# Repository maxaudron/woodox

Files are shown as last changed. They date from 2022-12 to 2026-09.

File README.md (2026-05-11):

# Woodox Firmware

Embedded Rust firmware for an analog hall-effect keyboard, targeting the RP2040 (Cortex-M0+). Runs bare-metal with `no_std`.

## Architecture

The firmware runs on both RP2040 cores simultaneously. Core 1 continuously scans hall-effect switches through analog multiplexers and ADC. Core 0 runs the USB HID stack and sends keyboard reports to the host at 1ms intervals. Switch state is shared between cores via static global memory, avoiding lock overhead.

## Workspace

The project is split into two crates:

### `board`

Hardware-specific code that directly interfaces with RP2040 peripherals.

- **`main.rs`** -- Entry point. Initializes clocks, GPIO pins, ADC, multiplexers, and the USB bus. Spawns the scan loop on core 1 and the USB loop on core 0.
- **`scan.rs`** -- Scan loop running on core 1. Iterates through all multiplexer channels, reads ADC values for each switch, and updates switch state.
- **`usb.rs`** -- USB loop running on core 0. Reads the global keyboard state every 1ms and sends NKRO HID reports to the host.
- **`hardware/mux.rs`** -- Driver for the CD74HC4067 16-channel analog multiplexer. Selects channels by setting four GPIO pins to the binary representation of the channel number.
- **`hardware/adc.rs`** -- Trait and implementation for reading raw values from the RP2040 ADC. Supports reading a single channel or all multiplexer inputs in sequence.
- **`dma.rs`** -- Work-in-progress DMA configuration for ADC transfers. Not currently used in the main loop.
- **`led/mod.rs`** -- Commented-out WS2812 LED driver using PIO. Not currently active.

### `library` (`woodox-lib`)

Platform-independent logic. Can be tested on the host machine.

- **`matrix/switch.rs`** -- Core switch logic. Each switch tracks its position, press/release state, and hold timing. Supports configurable actuation and release points. Implements rapid trigger, which dynamically fires press/release events based on relative travel distance rather than fixed thresholds.
- **`matrix/hall.rs`** -- Lookup table that converts raw 8-bit ADC values to physical travel distance in 0.1mm increments, based on the hall-effect sensor response curve.
- **`matrix/keys.rs`** -- Global keymap and keyboard state. Defines key types: regular keycodes, layer switching, layer-tap (layer on hold / keycode on tap), key-tap (keycode on hold / different keycode on tap), and grave-escape. Resolves key actions by walking down the layer stack.
- **`matrix/mod.rs`** -- Scan and ScanOrder structs that map physical switch positions (mux ID + channel) to their logical index in the keymap.
- **`layout/mod.rs`** -- Macros (`switches!`, `keymap!`, `layer!`, `key!`) for declaratively defining keyboard layouts at compile time.
- **`layout/macropad.rs`** -- Default layout for an 8-key macropad with 1 multiplexer. Defines the physical switch wiring and a two-layer keymap.

## Hardware

- **MCU**: RP2040 (dual Cortex-M0+ at 125 MHz, 12 MHz external crystal)
- **Switches**: Analog hall-effect sensors read via ADC
- **Multiplexers**: CD74HC4067 (16-channel analog mux), selecting switches for ADC reading
- **USB**: Native RP2040 USB with NKRO keyboard HID
- **LEDs**: WS2812 via PIO (currently disabled)

## Features

- `macropad` (default) -- Builds with the 8-key macropad layout.
- `timers` -- Enables microsecond-precision scan loop timing via the hardware timer.

## Building

Requires the `thumbv6m-none-eabi` target:

```sh
rustup target add thumbv6m-none-eabi
cargo build --release -p woodox
```

## Flashing

Uses `probe-run` via cargo runner, or `cargo-embed` with the provided `Embed.toml`:

```sh
cargo embed --release -p woodox
```

Debugger protocol is SWD at 20 MHz. RTT logging is enabled with `defmt` output.

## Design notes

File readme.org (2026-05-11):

#+title: Readme

* Decisions
** MUX controll central vs seperate
We can either control each mux on it's own, taking up significantly more pins
or have them be controlled all at the same time

- Much simpler routing
- less traces

- customize matrix scanning

** Split vs Lefty logic
either controller on each hand, or controller only on one hand

*** Split
- can use more mux
- lower latency?
- more keys
- mirror PCB

CD74HC4051
  
*** Lefty
- less cost
- simpler?
- analog signals over longer wire
  - potential interference?

- sepperate PCB designs
  
* TODOs
** TODO connect mux com only to uneven GPIO pins for PWM input
** DONE add pull up resistors to mux com
** DONE adjust value of drv5057
A3 uses ~25% of the messuring range in one direction
A2 would use ~50%
A1 would use 100%, but might clip.
** DONE switch to drv5056A2
** TODO Use same pins for all mux selects
** TODO matrix to keycode conversion
** TODO usb hid impl
https://github.com/dlkj/usbd-human-interface-device

* Magnet distance lookup table
3.25V VCC
3.00V @ 2.25mm = 24.12mT
0.95V @ 6.25mm =  3.52mT

#+begin_src python :python3.10 :results output
import math

R = 1.75
D = 4
z = 2.25
r = 24.12
B = - ( (2*r) / ( ( z / math.sqrt( (R**2) + (z**2) )) - ( (D+z) / math.sqrt( (R**2) + ((D+z)**2) ) ) ) )
print(B)
#+end_src

#+RESULTS:
: 277.8612937046934

** lookup table
#+begin_src python :python python3.10 :results output
import math
import numpy as np

Z = np.linspace(0.1, 10, 100)
B = 0.38
R = 1.75
D = 4

def flux(z):
    return (((B/2)*( ( (D+z) / math.sqrt((R**2) + ((D+z)**2)) )  -  ( z / math.sqrt((R**2)+(z**2)) )))*1000)

def voltage(x):
    return (600 + x * (100))

def value(x):
    return x / (3300.0 / 256.0)

flux_vec = np.vectorize(flux)
voltage_vec = np.vectorize(voltage)
value_vec = np.vectorize(value)

prev = 0
for z in Z:
    z = round(z, 2)
    y = float(flux_vec(z))
    v = float(voltage_vec(y))
    value = float(value_vec(v))
    value = round(value)
    print(str(value) + "..=" + str(prev-1) + " => " + str(int(z * 10)) + ",")
    prev = value
#+end_src

#+RESULTS:
#+begin_example
1318..=-1 => 1,
1240..=1317 => 2,
1163..=1239 => 3,
1088..=1162 => 4,
1015..=1087 => 5,
946..=1014 => 6,
880..=945 => 7,
819..=879 => 8,
761..=818 => 9,
706..=760 => 10,
656..=705 => 11,
610..=655 => 12,
567..=609 => 13,
528..=566 => 14,
492..=527 => 15,
459..=491 => 16,
429..=458 => 17,
401..=428 => 18,
375..=400 => 19,
352..=374 => 20,
331..=351 => 21,
312..=330 => 22,
294..=311 => 23,
277..=293 => 24,
262..=276 => 25,
248..=261 => 26,
236..=247 => 27,
224..=235 => 28,
213..=223 => 29,
203..=212 => 30,
194..=202 => 31,
186..=193 => 32,
178..=185 => 33,
170..=177 => 34,
164..=169 => 35,
157..=163 => 36,
151..=156 => 37,
146..=150 => 38,
141..=145 => 39,
136..=140 => 40,
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
#+end_example

** graph
#+NAME: magnets
|       B |    R | D |
|---------+------+---|
|    0.38 | 1.75 | 4 |
|    0.28 | 1.75 | 4 |

#+begin_src python :python python3.10 :results file :exports both :var data=magnets
import math
import matplotlib.pyplot as plt
import numpy as np

for line in data:
    Z = np.linspace(0.1, 10, 100)
    B = line[0]
    R = line[1]
    D = line[2]

    def f(z):
        r = (((B/2)*( ( (D+z) / math.sqrt((R**2) + ((D+z)**2)) )  -  ( z / math.sqrt((R**2)+(z**2)) )))*1000)
        if z == 2.0:
            plt.annotate('A=' + str(z) + "," + str(round(r, 2)), xy=(z, r), xytext=(z+1, r+1))
        if z == 6.3:
            plt.annotate('B=' + str(z) + "," + str(round(r, 2)), xy=(z, r), xytext=(z+1, r+1))
        return r

    x = np.vectorize(f)
    plt.plot(Z, x(Z), label="B = " + str(B))

plt.xlabel("mm")
plt.ylabel("mT")
plt.legend()
filename = "plot.png"
plt.savefig(filename)
return(filename)
#+end_src

#+RESULTS:


* Parts
LED Controller https://jlcpcb.com/partdetail/3305937-IS31FL3741A_QFLS4TR/C2940604

Multiplexer https://www.ti.com/lit/ds/symlink/cd74hc4067.pdf

Example rp2040 usage https://proto-pic.co.uk/content/RPI-PICO-R3-PUBLIC-SCHEMATIC.pdf

rp2040 https://datasheets.raspberrypi.com/rp2040/rp2040-datasheet.pdf

** Hall Sensor
https://www.ti.com/sensors/magnetic-sensors/linear-hall-effect-sensors/overview.html

DRV5055A3 SOT-23
https://www.ti.com/lit/ds/symlink/drv5055.pdf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

35 keys per side

DRV5057
https://www.ti.com/lit/ds/symlink/drv5057.pdf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

https://www.digikey.de/en/product-highlight/s/sunled/reverse-mount-rgb-plcc-smd-led

13,200 Gauss
1320mT

3.5mm diameter x 4 thiccness
z from 2.25mm to 6.25mm

Divide[13200,2](Divide[D + 4mm,Sqrt[Power[\(40)0.5 * 3.5mm\(41),2]+ \(40)D + 4mm\(41)]] - Divide[D,Sqrt[Power[\(40)0.5 * 3.5mm\(41),2]+ Power[D,2]]])

#+begin_src gnuplot
B = 1480
C = 4.7625
T = 12.7

plot [D = -20 :20] (B/2)*( ( ( D + T ) / sqrt( (0.5*C)**2 + (D+T)**2 ) ) - ( D / sqrt(0.5*C)**2 + D**2 ) )
#+end_src

https://crocus-technology.com/basic-magnetic-field-calculator/

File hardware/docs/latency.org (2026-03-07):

#+title: Latency

* Thought dumb
#+begin_src
[00:14:40] <+audron> well, this latency messuring stuff is a bit more complicated
[00:15:16] <+audron> the on-chip timer does an ok job but i have random outliers that i'm not sure with
[00:15:38] <+audron> that could either be somethings really stupid i did, or just be random
[00:17:59] <+audron> the switch scanning loop i'm messuring is on a sepperate core and should be pretty much totally isolated but there might still be some weird interactions by the timer registers themsselfs, or the logging / formatting library
[00:18:31] <+audron> and messuring off-device is a meh buisness too
[00:19:02] <+audron> some other guys i've read messure the whole round trip off caps-lock pressed, os working on it, and the led change reported back
[00:19:38] <+audron> which i guess is fine to compare latency between units on the same setup, but is entirely uncomparable between systems
[00:20:07] <+audron> and also non of the ones i've seen thus far actually test how the system reacts with multiple button presses
[00:20:28] <+audron> guess i gotta make my own...
[00:20:31] -*- audron sighs
#+end_src

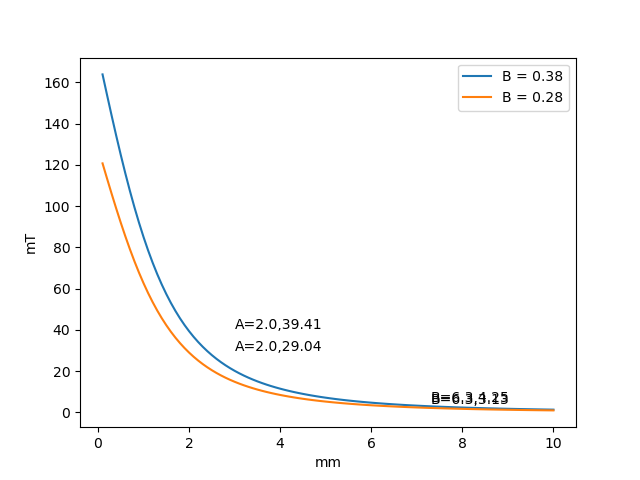
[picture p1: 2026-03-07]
hardware/docs/distance_magnetic_plot.png

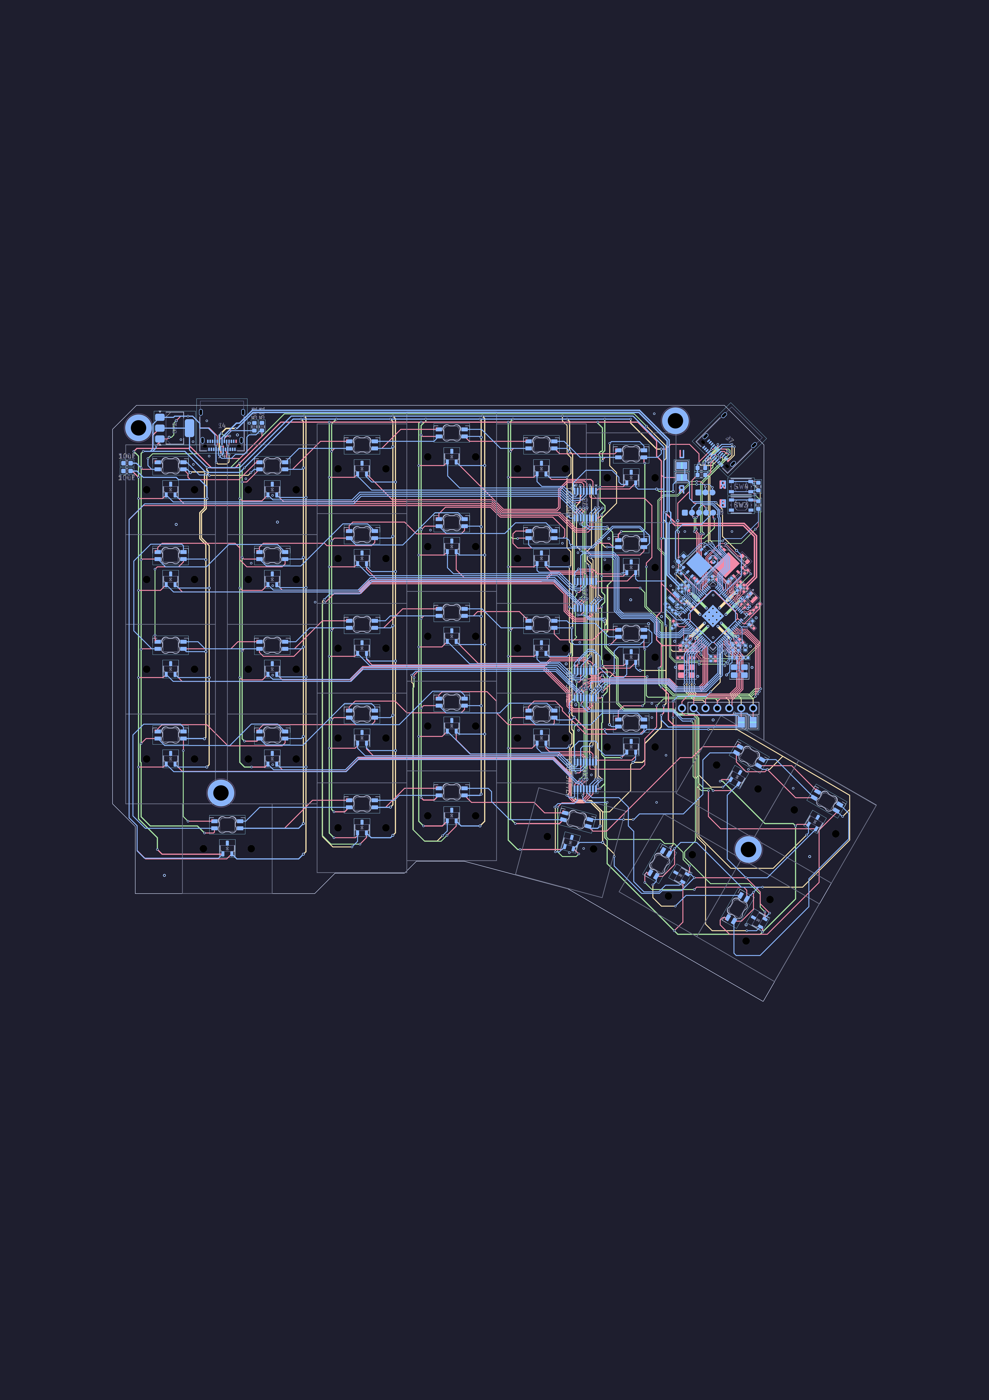
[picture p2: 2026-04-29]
hardware/woodox/pcb.webp

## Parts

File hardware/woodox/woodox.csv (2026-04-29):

Reference | Qty | Value | IPN | DNP | Exclude from BOM | Exclude from Board | Footprint | Datasheet | MPN | Manufacturer_Name | Manufacturer_Part_Number
Y2,Y3 | 2 | ABM8-272-T3 | CLK-000062 |  |  |  | Crystal:Crystal_SMD_3225-4Pin_3.2x2.5mm
U64,U79 | 2 | RP2350_80QFN | ICS-000063 |  |  |  | RP2350_80QFN_minimal:RP2350-QFN-80-1EP_10x10_P0.4mm_EP3.4x3.4mm_ThermalVias
U34,U35,U36,U37,U73,U74,U75,U76 | 8 | 74HC4051 | ICS-000064 |  |  |  | Package_SO:TSSOP-16_4.4x5mm_P0.65mm | http://www.ti.com/lit/ds/symlink/cd74hc4051.pdf | CD74HC4051PWR
U33,U72 | 2 | NCP1117-3.3_SOT223 | PWR-000043 |  |  |  | Package_TO_SOT_SMD:SOT-223-3_TabPin2 | http://www.onsemi.com/pub_link/Collateral/NCP1117-D.PDF | NCP1117LPST33T3G
U25,U49 | 2 | W25Q128JVP | ICS-000065 |  |  |  | Package_SON:WSON-8-1EP_6x5mm_P1.27mm_EP3.4x4.3mm | http://www.winbond.com/resource-files/w25q128jv_dtr%20revc%2003272018%20plus.pdf
U10 | 1 | OLED_256x64_I2C | MIS-000056 |  |  |  | lib:OLED_256x64_I2C |  | HEADER
U1,U2,U3,U4,U5,U6,U7,U8,U9,U11,U12,U13,U14,U15,U16,U17,U18,U19,U20,U21,U22,U23,U24,U26,U27,U28,U29,U30,U31,U32,U38,U39,U40,U41,U42,U43,U44,U45,U46,U47,U48,U50,U51,U52,U53,U54,U55,U56,U57,U58,U59,U60,U61,U62,U63,U65,U66,U67,U68,U69,U70,U71,U77,U78 | 64 | DRV5057A3 | ICS-000049 |  |  |  | lib:DRV505x | https://www.ti.com/lit/ds/symlink/drv5057.pdf | DRV5057A3
SW1,SW2,SW3,SW4 | 4 | SW_Push | MEC-000040 |  |  |  | Button_Switch_SMD:SW_Push_1P1T_NO_Vertical_Wuerth_434133025816
R24,R25,R27,R28 | 4 | 27 | RES-000070 |  |  |  | Resistor_SMD:R_0402_1005Metric
R22,R26 | 2 | 33 | RES-000071 |  |  |  | Resistor_SMD:R_0402_1005Metric
R17,R18,R19,R20 | 4 | 56k | RES-000072 |  |  |  | Resistor_SMD:R_0402_1005Metric |  | ERJ-3EKF1002V
R11,R13 | 2 | DNF |  | DNP |  |  | Resistor_SMD:R_0402_1005Metric |  | ERJ-3EKF1002V
R6,R7,R14,R15 | 4 | 5k1 | RES-000015 |  |  |  | Resistor_SMD:R_0402_1005Metric |  | ERJ-3EKF5101V
R1,R2,R12,R16,R21,R23 | 6 | 1k | RES-000011 |  |  |  | Resistor_SMD:R_0402_1005Metric
LED1,LED2,LED3,LED4,LED5,LED6,LED7,LED8,LED9,LED10,LED11,LED12,LED13,LED14,LED15,LED16,LED17,LED18,LED19,LED20,LED21,LED22,LED23,LED24,LED25,LED26,LED27,LED28,LED29,LED30,LED31,LED32,LED33,LED34,LED35,LED36,LED37,LED38,LED39,LED40,LED41,LED42,LED43,LED44,LED45,LED46,LED47,LED48,LED49,LED50,LED51,LED52,LED53,LED54,LED55,LED56,LED57,LED58,LED59,LED60,LED61,LED62,LED63,LED64 | 64 | MX_SK6812MINI-E | DIO-000012 |  |  |  | lib:LED_MX_SK6812MINI-R |  | SK6812MINI-E
L2,L3 | 2 | 3.3u | IND-000067 |  |  |  | RP2350_80QFN_minimal:L_pol_2016 |  | AOTA-B201610S3R3-101-T
J6,J7 | 2 | USB_C_Interlink | CON-000041 |  |  |  | Connector_USB:USB_C_Receptacle_Amphenol_12401610E4-2A | https://www.usb.org/sites/default/files/documents/usb_type-c.zip | 12401832E402A
J2,J4 | 2 | USB_C_To_Host | CON-000041 |  |  |  | Connector_USB:USB_C_Receptacle_Amphenol_12401610E4-2A | https://www.usb.org/sites/default/files/documents/usb_type-c.zip | 12401832E402A
C40,C41,C42,C43 | 4 | 15p | CAP-000069 |  |  |  | Capacitor_SMD:C_0402_1005Metric
C14,C17,C24,C25 | 4 | 4.7u | CAP-000024 |  |  |  | Capacitor_SMD:C_0402_1005Metric
C12,C13,C21,C22 | 4 | 4.7u | CAP-000024 |  |  |  | RP2350_80QFN_minimal:C_0402_1005Metric_small_pads
C6,C10,C16,C20 | 4 | 10uF | CAP-000021 |  |  |  | Capacitor_SMD:C_0402_1005Metric |  | GRM155R60J106ME15D
C4,C5,C15,C18,C19,C23,C26,C27,C32,C33,C34,C35,C36,C37,C38,C39,C44,C45,C46,C47,C48,C49,C50,C51 | 24 | 100n | CAP-000025 |  |  |  | Capacitor_SMD:C_0402_1005Metric

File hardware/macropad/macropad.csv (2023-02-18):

Item | Qty | Reference(s) | Value | LibPart | Footprint | Datasheet | Description | Height | MPN | Manufacturer_Name | Manufacturer_Part_Number | Mouser Part Number | Mouser Price/Stock
1 | 10 | C1, C7, C8, C9, C10, C12, C13, C14, C15, C16 | 0.1uF | Device:C_Small | Capacitor_SMD:C_0402_1005Metric | ~
2 | 2 | C2, C3 | 27pF | Device:C_Small | Capacitor_SMD:C_0402_1005Metric | ~
3 | 2 | C4, C5 | 1uF | Device:C_Small | Capacitor_SMD:C_0402_1005Metric | ~
4 | 2 | C6, C11 | 10uF | pspice:CAP | Capacitor_SMD:C_0402_1005Metric | ~
5 | 1 | IC1 | W25Q16JVUXIQ_TR | W25Q16JVUXIQ_TR:W25Q16JVUXIQ_TR | W25Q16JVUXIQ_TR:SON50P300X200X60-9N | https://componentsearchengine.com/Datasheets/1/W25Q16JVUXIQ TR.pdf | NOR Flash spiFlash, 3V, 16M-bit, 4Kb Uniform Sector, DTR | 0.6 | W25Q16JVUXIQ TR | Winbond | W25Q16JVUXIQ TR | 454-W25Q16JVUXIQTR | https://www.mouser.co.uk/ProductDetail/Winbond/W25Q16JVUXIQ-TR?qs=qSfuJ%252Bfl%2Fd7SDdIHLGOd1g%3D%3D
6 | 1 | J1 | Conn_01x03_Female | Connector:Conn_01x04_Female | Connector_PinHeader_2.54mm:PinHeader_1x04_P2.54mm_Vertical | ~
7 | 1 | J2 | USB_C_Receptacle | Connector:USB_C_Receptacle | Connector_USB:USB_C_Receptacle_Amphenol_12401610E4-2A | https://www.usb.org/sites/default/files/documents/usb_type-c.zip |  |  | 12401610E4#2A
8 | 6 | LED1, LED2, LED3, LED4, LED5, LED6 | MX_SK6812MINI-E | marbastlib-mx:MX_SK6812MINI-E | marbastlib-mx:LED_MX_6028R |  |  |  | SK6812MINI-E
9 | 3 | R1, R3, R8 | 1k | Device:R | Resistor_SMD:R_0603_1608Metric | ~
10 | 1 | R2 | 10k | Device:R | Resistor_SMD:R_0603_1608Metric | ~
11 | 2 | R4, R5 | 27.4 | Device:R | Resistor_SMD:R_0603_1608Metric | ~
12 | 2 | R6, R7 | 5k1 | Device:R | Resistor_SMD:R_0603_1608Metric | ~
13 | 1 | SW1 | BOOT | Switch:SW_Push | Button_Switch_SMD:SW_Push_1P1T_NO_6x6mm_H9.5mm | ~ |  |  | 95C06B2GWRT
14 | 1 | SW2 | RESET | Switch:SW_Push | Button_Switch_SMD:SW_Push_1P1T_NO_6x6mm_H9.5mm | ~ |  |  | 95C06B2GWRT
15 | 1 | U1 | RP2040 | MCU_RaspberryPi:RP2040 | Package_DFN_QFN:QFN-56-1EP_7x7mm_P0.4mm_EP3.2x3.2mm | https://datasheets.raspberrypi.com/rp2040/rp2040-datasheet.pdf |  |  | RPI Chip RP2040-7-500
16 | 6 | U2, U3, U4, U5, U7, U8 | DRV5057A3 | Sensor_Magnetic:DRV5055A3xDBZxQ1 | lib:DRV5057A3_K | https://www.ti.com/lit/ds/symlink/drv5057.pdf |  |  | DRV5057A3QDBZT
17 | 1 | U6 | CD74HC4067M | 74xx:CD74HC4067M | Package_SO:SOIC-24W_7.5x15.4mm_P1.27mm | http://www.ti.com/lit/ds/symlink/cd74hc4067.pdf |  |  | CD74HC4067SM96E4
18 | 1 | U9 | NCP1117-3.3_SOT223 | Regulator_Linear:NCP1117-3.3_SOT223 | Package_TO_SOT_SMD:SOT-223-3_TabPin2 | http://www.onsemi.com/pub_link/Collateral/NCP1117-D.PDF |  |  | NCP1117ST33T3G
19 | 1 | Y1 | ABLS-12.000MHZ-B4-T | Device:Crystal | Crystal:Crystal_SMD_5032-2Pin_5.0x3.2mm | https://www.mouser.de/datasheet/2/3/abls-1664338.pdf |  |  | ABLS-12.000MHZ-B4-T

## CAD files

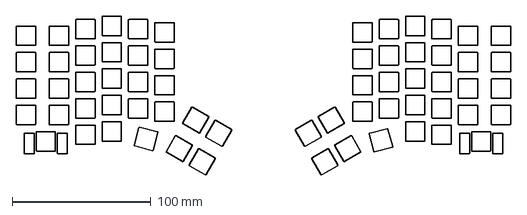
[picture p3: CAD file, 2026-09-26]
hardware/keyboard-plate.dxf
356.9 x 114.5 mm

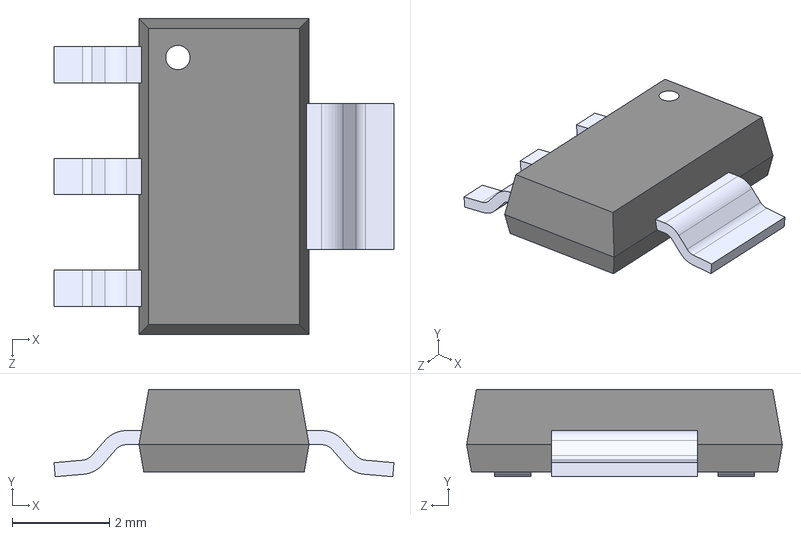
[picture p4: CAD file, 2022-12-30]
hardware/kicad_lib/LM3940IMPX-3.3_NOPB.step
7.00 x 1.80 x 6.50 mm

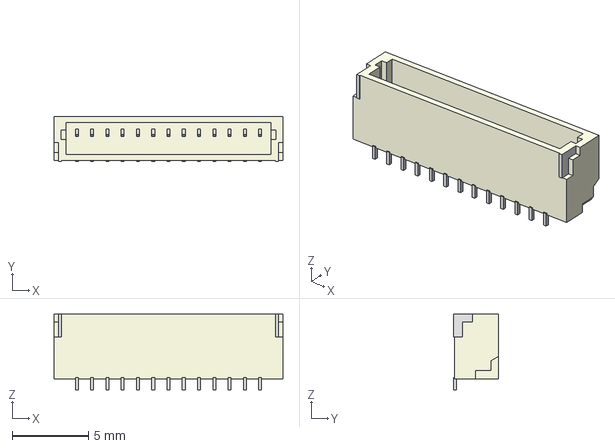
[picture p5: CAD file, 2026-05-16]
hardware/kicad_lib/marbastlib/3d/CON_SM13B-SRSS-TB.step
15.0 x 2.96 x 4.95 mm

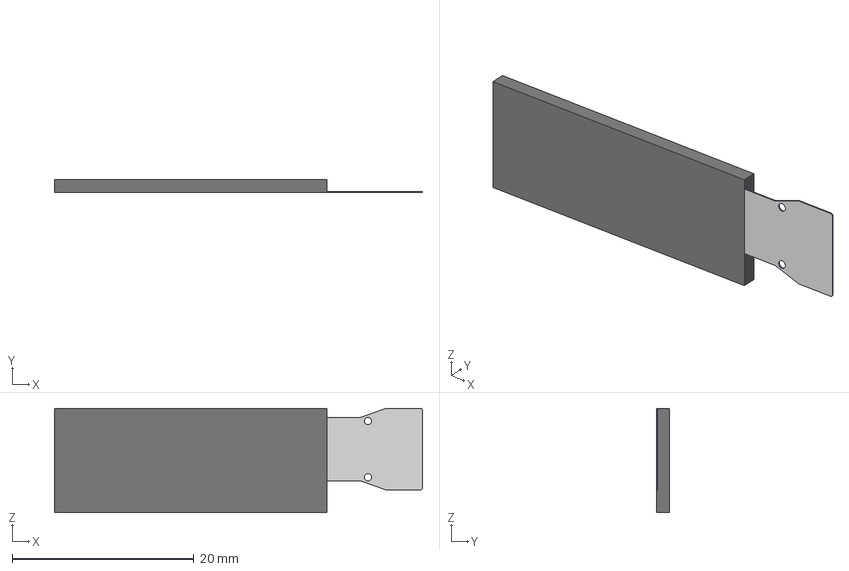
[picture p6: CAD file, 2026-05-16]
hardware/kicad_lib/oled/SSD1306_OLED-0.91-128x32.step
40.5 x 1.45 x 11.5 mm

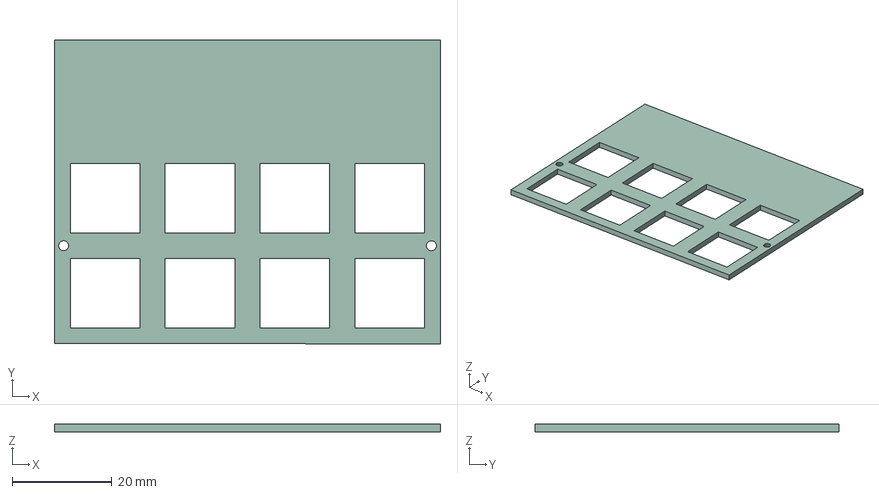
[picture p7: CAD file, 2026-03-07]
hardware/macropad/plate.step
77.5 x 60.9 x 1.58 mm

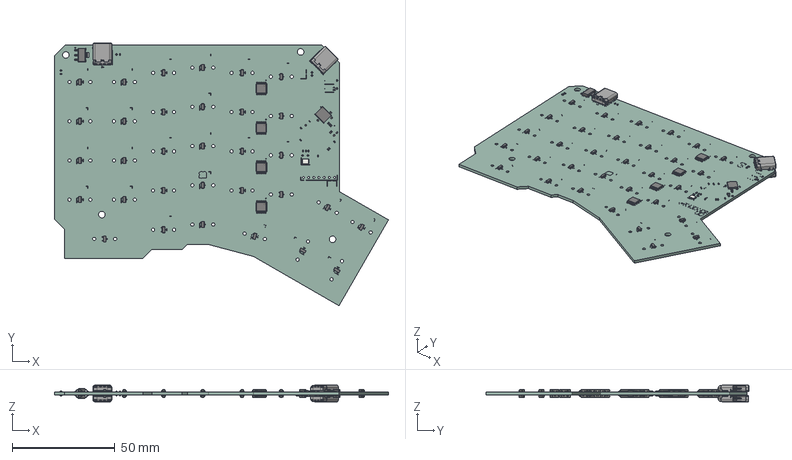
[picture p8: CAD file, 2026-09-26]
hardware/woodox/woodox.step
162.2 x 127.5 x 8.19 mm
SOT-23 x 64
R_0402_1005Metric x 22
C_0402_1005Metric x 40
Crystal_SMD_3225-4Pin_3.2x2.5mm x 2
SOT-223 x 2
WSON-8-1EP_6x5mm_P1.27mm_EP3.4x4.3mm x 2
TSSOP-16_4.4x5mm_P0.65mm x 8
USB_C_Receptacle_Amphenol_12401610E4-2A x 4
woodox_silkscreen x 2
woodox_PCB_1
woodox_PCB_2
woodox_PCB_3
woodox_PCB_4
woodox_PCB_5
woodox_PCB_6
woodox_PCB_7
woodox_PCB_8
woodox_PCB_9
woodox_PCB_10
woodox_PCB_11
woodox_PCB_12
woodox_PCB_13
woodox_PCB_14
woodox_PCB_15
woodox_PCB_16
woodox_PCB_17
woodox_PCB_18
woodox_PCB_19
woodox_PCB_20
woodox_PCB_21
woodox_PCB_22
woodox_PCB_23
woodox_PCB_24
woodox_PCB_25
woodox_PCB_26
woodox_PCB_27

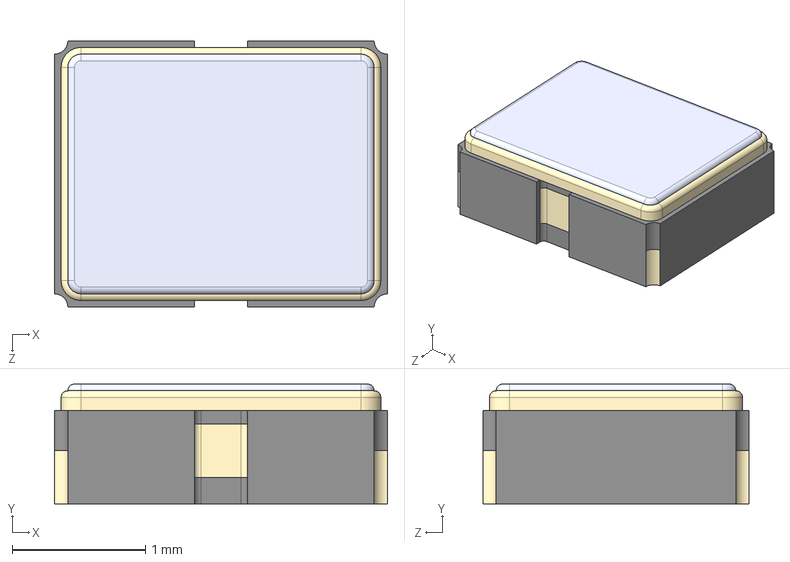
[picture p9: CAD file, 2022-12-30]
hardware/kicad_lib/ECS-2520MV-080-CN-TR.step
2.50 x 0.9 x 2.00 mm

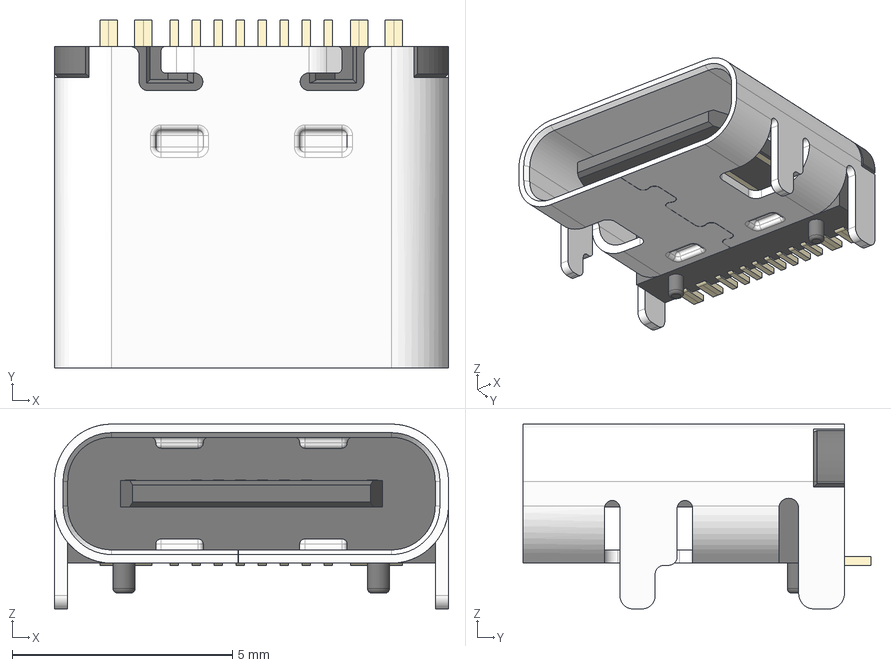
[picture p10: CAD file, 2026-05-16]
hardware/kicad_lib/marbastlib/3d/CON_TYPE-C-31-M-12.step
8.95 x 7.90 x 4.20 mm
ConPins
PcbPins
Mold
Frame

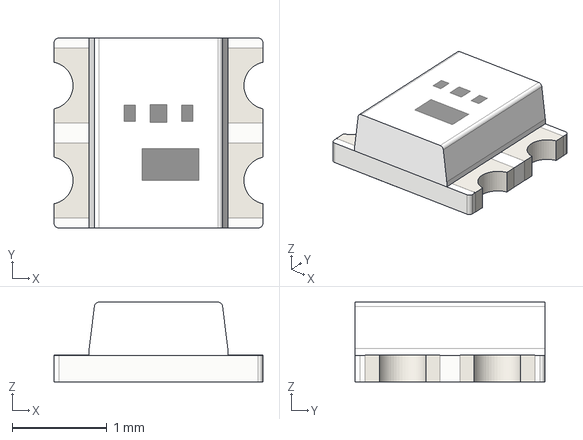
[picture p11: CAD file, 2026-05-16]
hardware/kicad_lib/marbastlib/3d/LED_WS2812_2020.step
2.20 x 2.00 x 0.842 mm

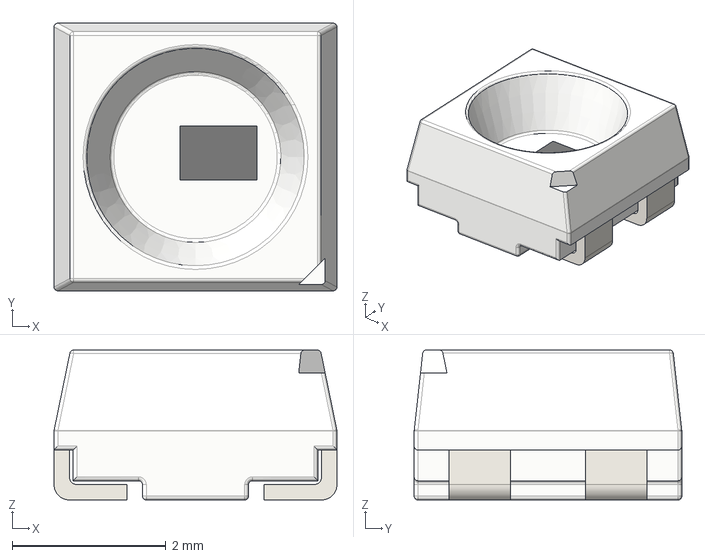
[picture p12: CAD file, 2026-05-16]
hardware/kicad_lib/marbastlib/3d/LED_WS2812B-MINI.step
3.68 x 3.48 x 1.95 mm

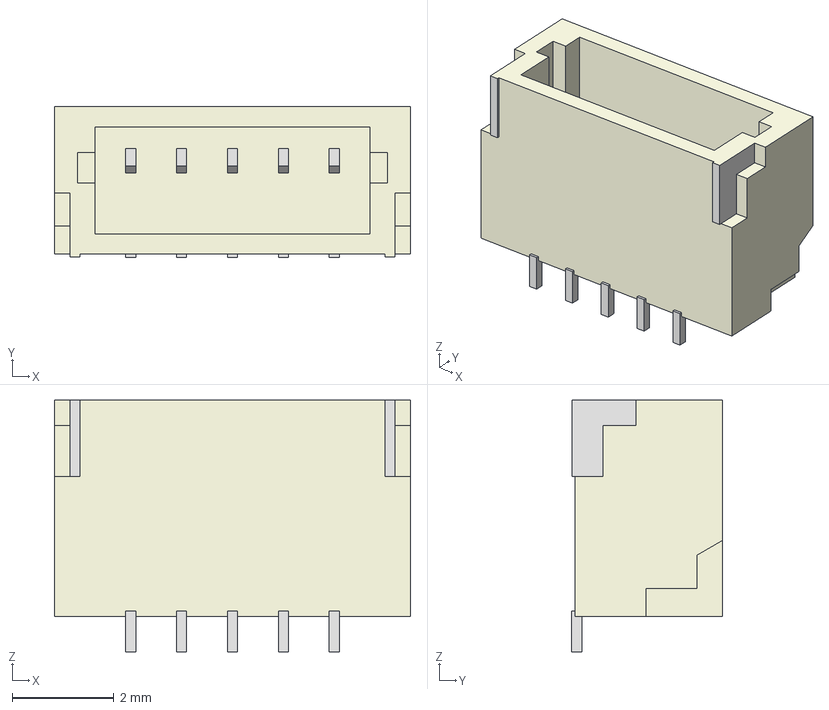
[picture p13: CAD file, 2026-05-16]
hardware/kicad_lib/marbastlib/3d/CON_SM05B-SRSS-TB.step
7.00 x 2.96 x 4.95 mm

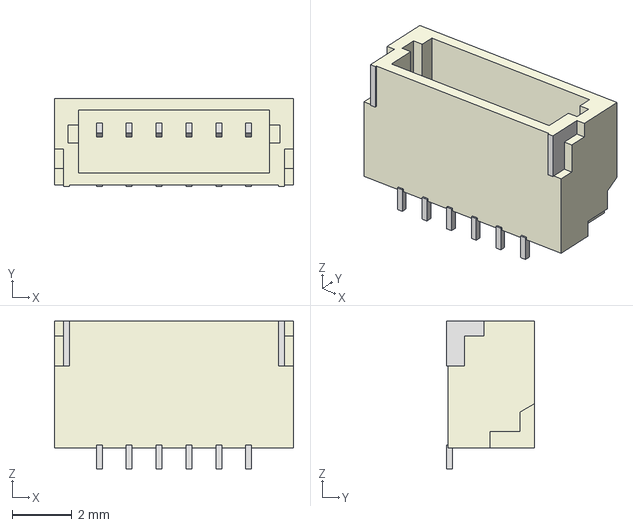
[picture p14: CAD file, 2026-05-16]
hardware/kicad_lib/marbastlib/3d/CON_SM06B-SRSS-TB.step
8.00 x 2.96 x 4.95 mm

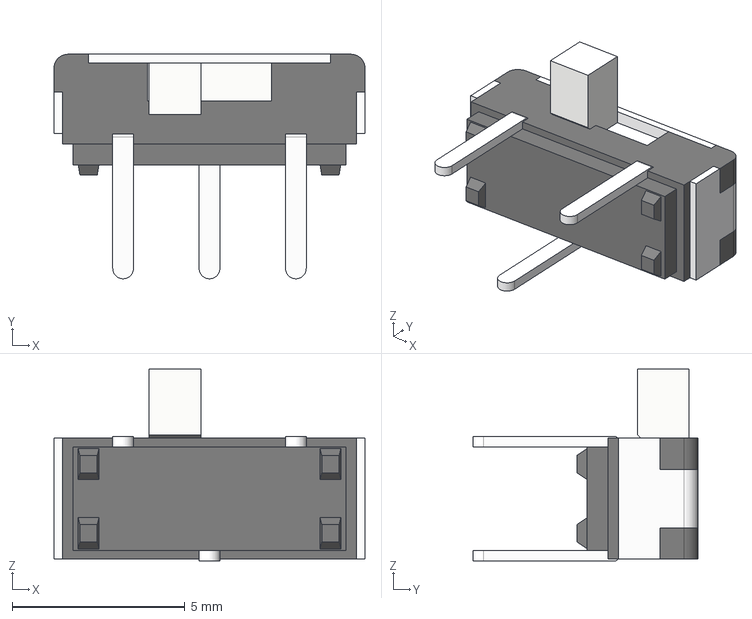
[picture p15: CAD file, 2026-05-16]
hardware/kicad_lib/marbastlib/3d/SW_SSSS213100.step
9.00 x 6.50 x 5.55 mm

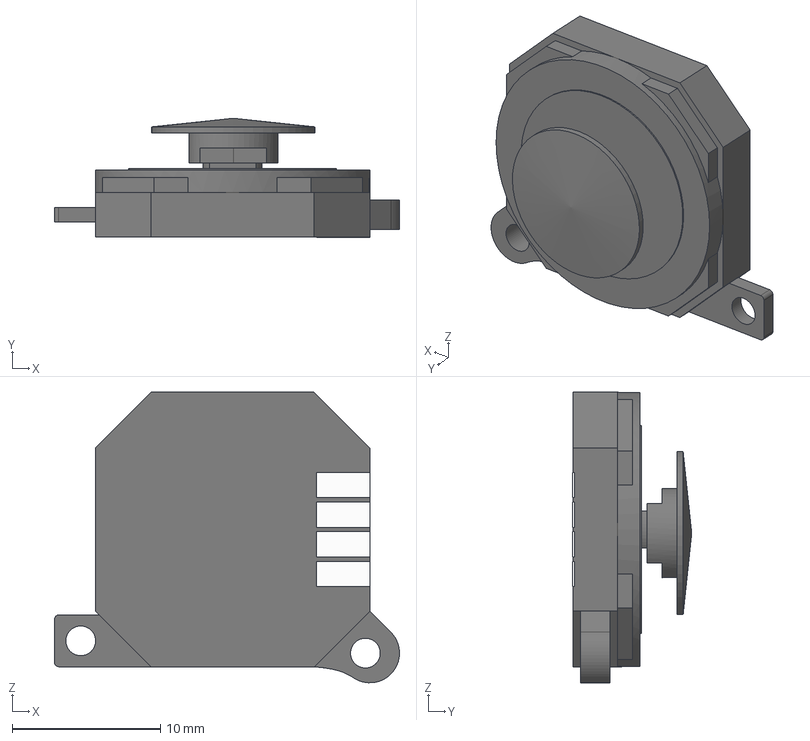
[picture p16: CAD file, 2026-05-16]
hardware/kicad_lib/marbastlib/3d/PNT_psp1000.step
23.2 x 8.05 x 19.6 mm

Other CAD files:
hardware/kicad_lib/marbastlib/3d/CON_MJ-4PP-9.step
hardware/kicad_lib/marbastlib/3d/HS_Kailh_MX.step
hardware/kicad_lib/marbastlib/3d/CON_TYPE-C-31-M-14.step
hardware/kicad_lib/marbastlib/3d/PNT_RKJXU1210006.step
hardware/kicad_lib/marbastlib/3d/CON_BM02B-ACHSS.step
hardware/kicad_lib/marbastlib/3d/CON_SM02B-SRSS-TB.step
hardware/kicad_lib/marbastlib/3d/CON_SM04B-SRSS-TB.step
hardware/kicad_lib/marbastlib/3d/CON_SM07B-SRSS-TB.step
hardware/kicad_lib/marbastlib/3d/CON_SM08B-SRSS-TB.step
hardware/kicad_lib/marbastlib/3d/Crystal_FA-128.step
hardware/kicad_lib/marbastlib/3d/HS_Kailh_Choc.step
hardware/kicad_lib/marbastlib/3d/LED_SK6812MINI-E.step
hardware/kicad_lib/marbastlib/3d/MSK12C02.step
hardware/kicad_lib/marbastlib/3d/ROT_EC11E.step
hardware/kicad_lib/marbastlib/3d/ROT_EC11N.step
hardware/kicad_lib/marbastlib/3d/SW_ESP3020.step
hardware/kicad_lib/marbastlib/3d/SW_MSK12C02.step
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

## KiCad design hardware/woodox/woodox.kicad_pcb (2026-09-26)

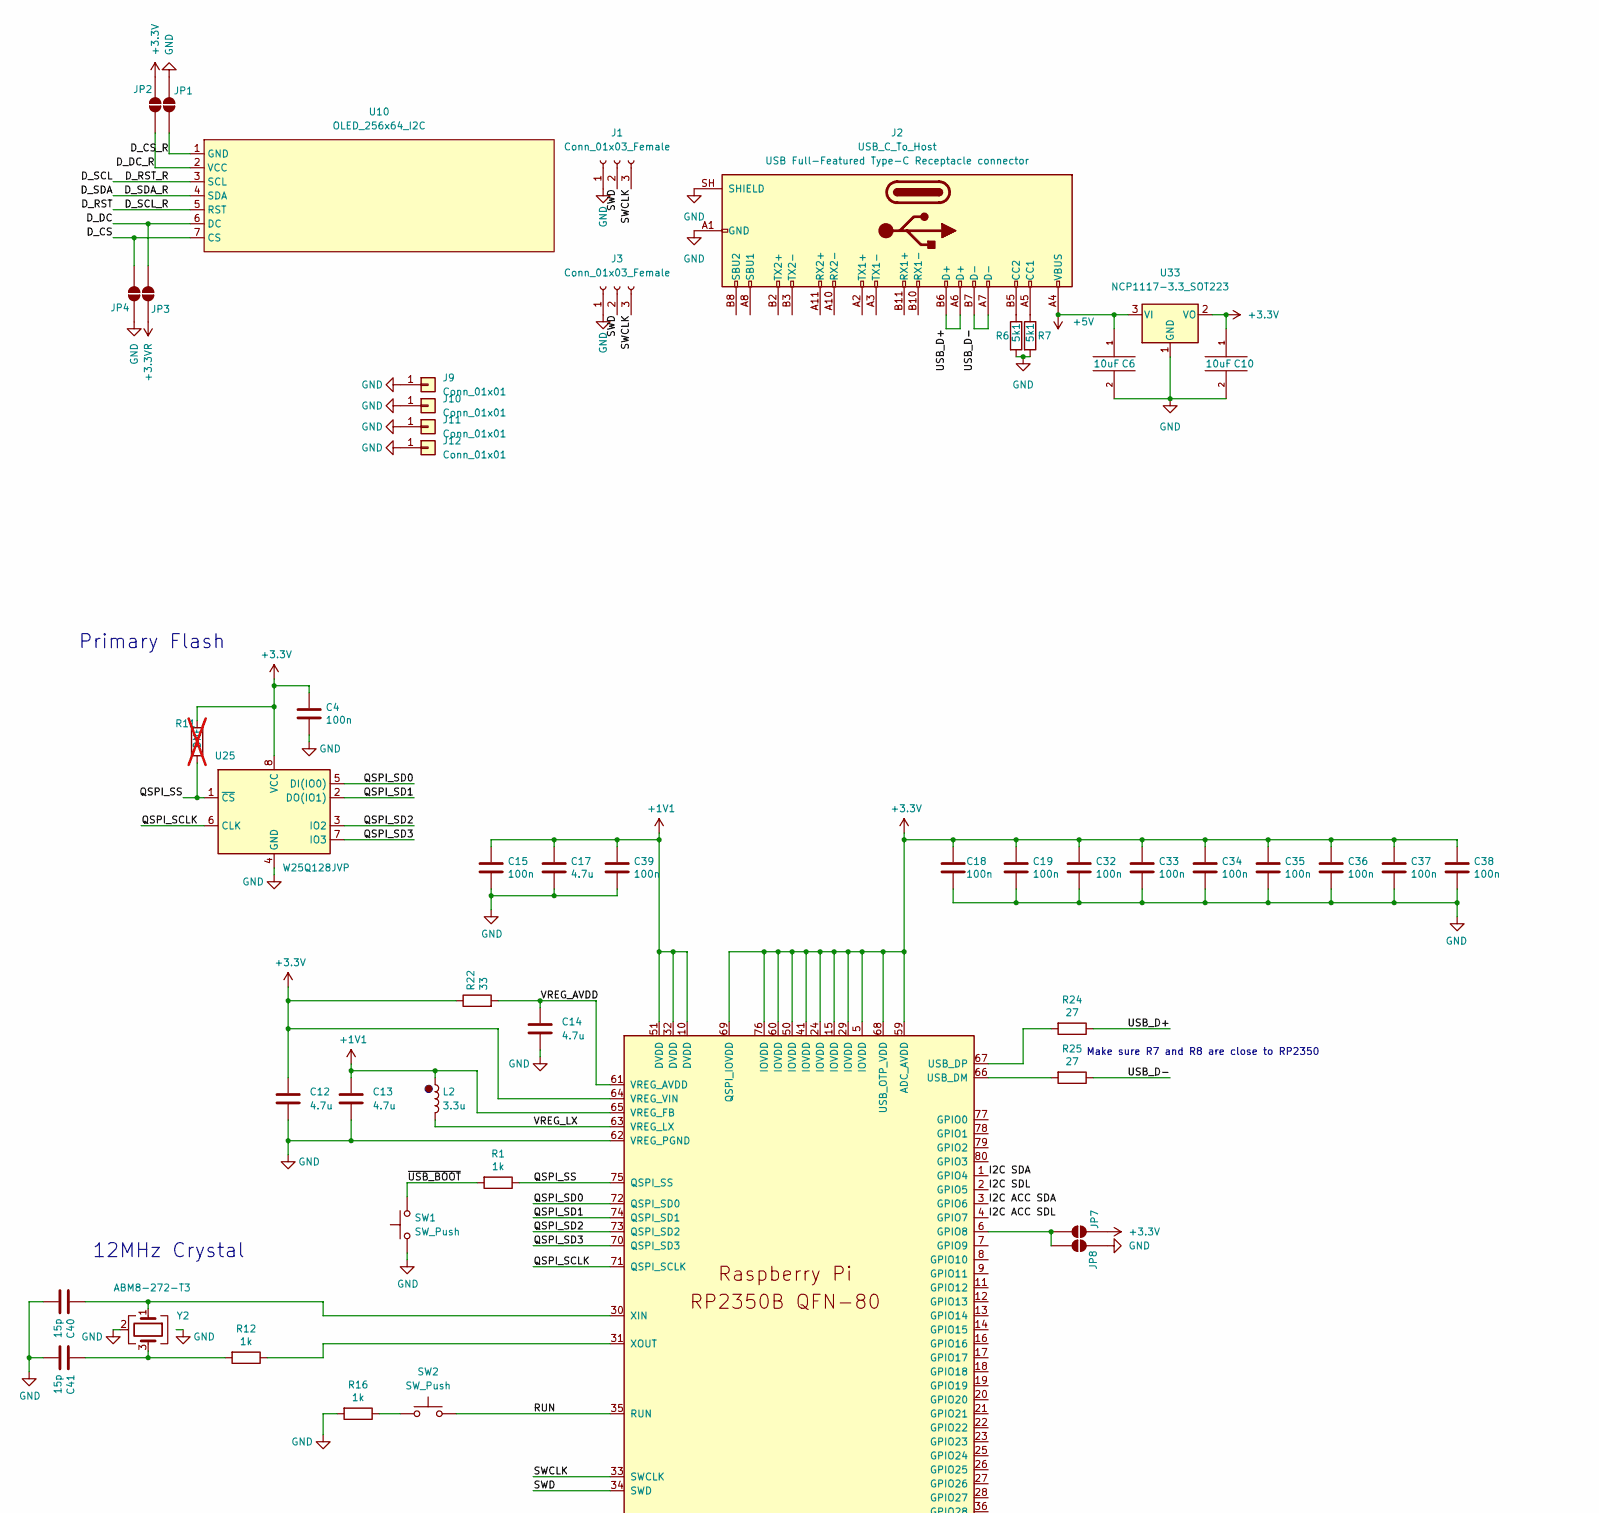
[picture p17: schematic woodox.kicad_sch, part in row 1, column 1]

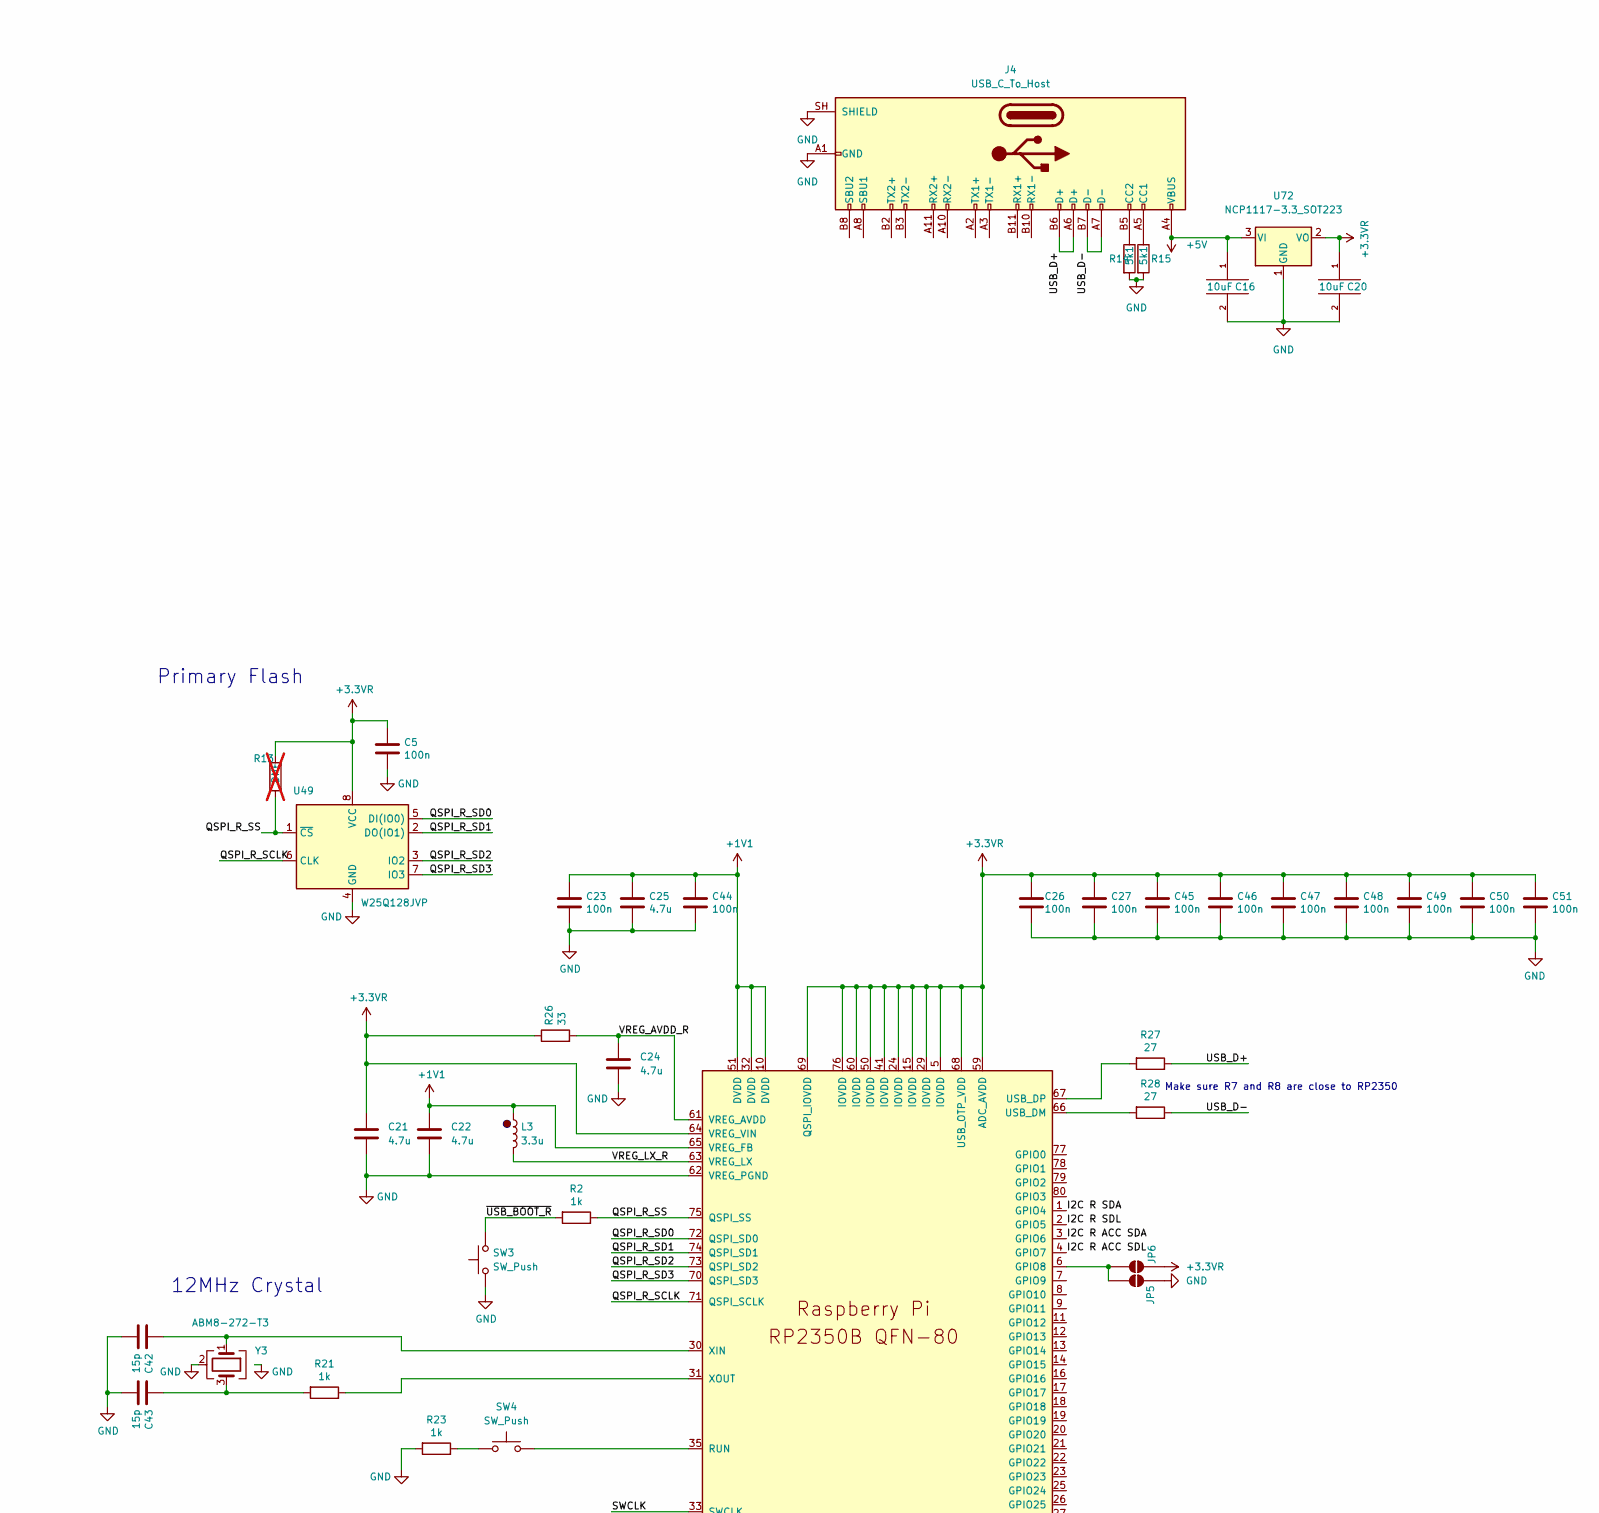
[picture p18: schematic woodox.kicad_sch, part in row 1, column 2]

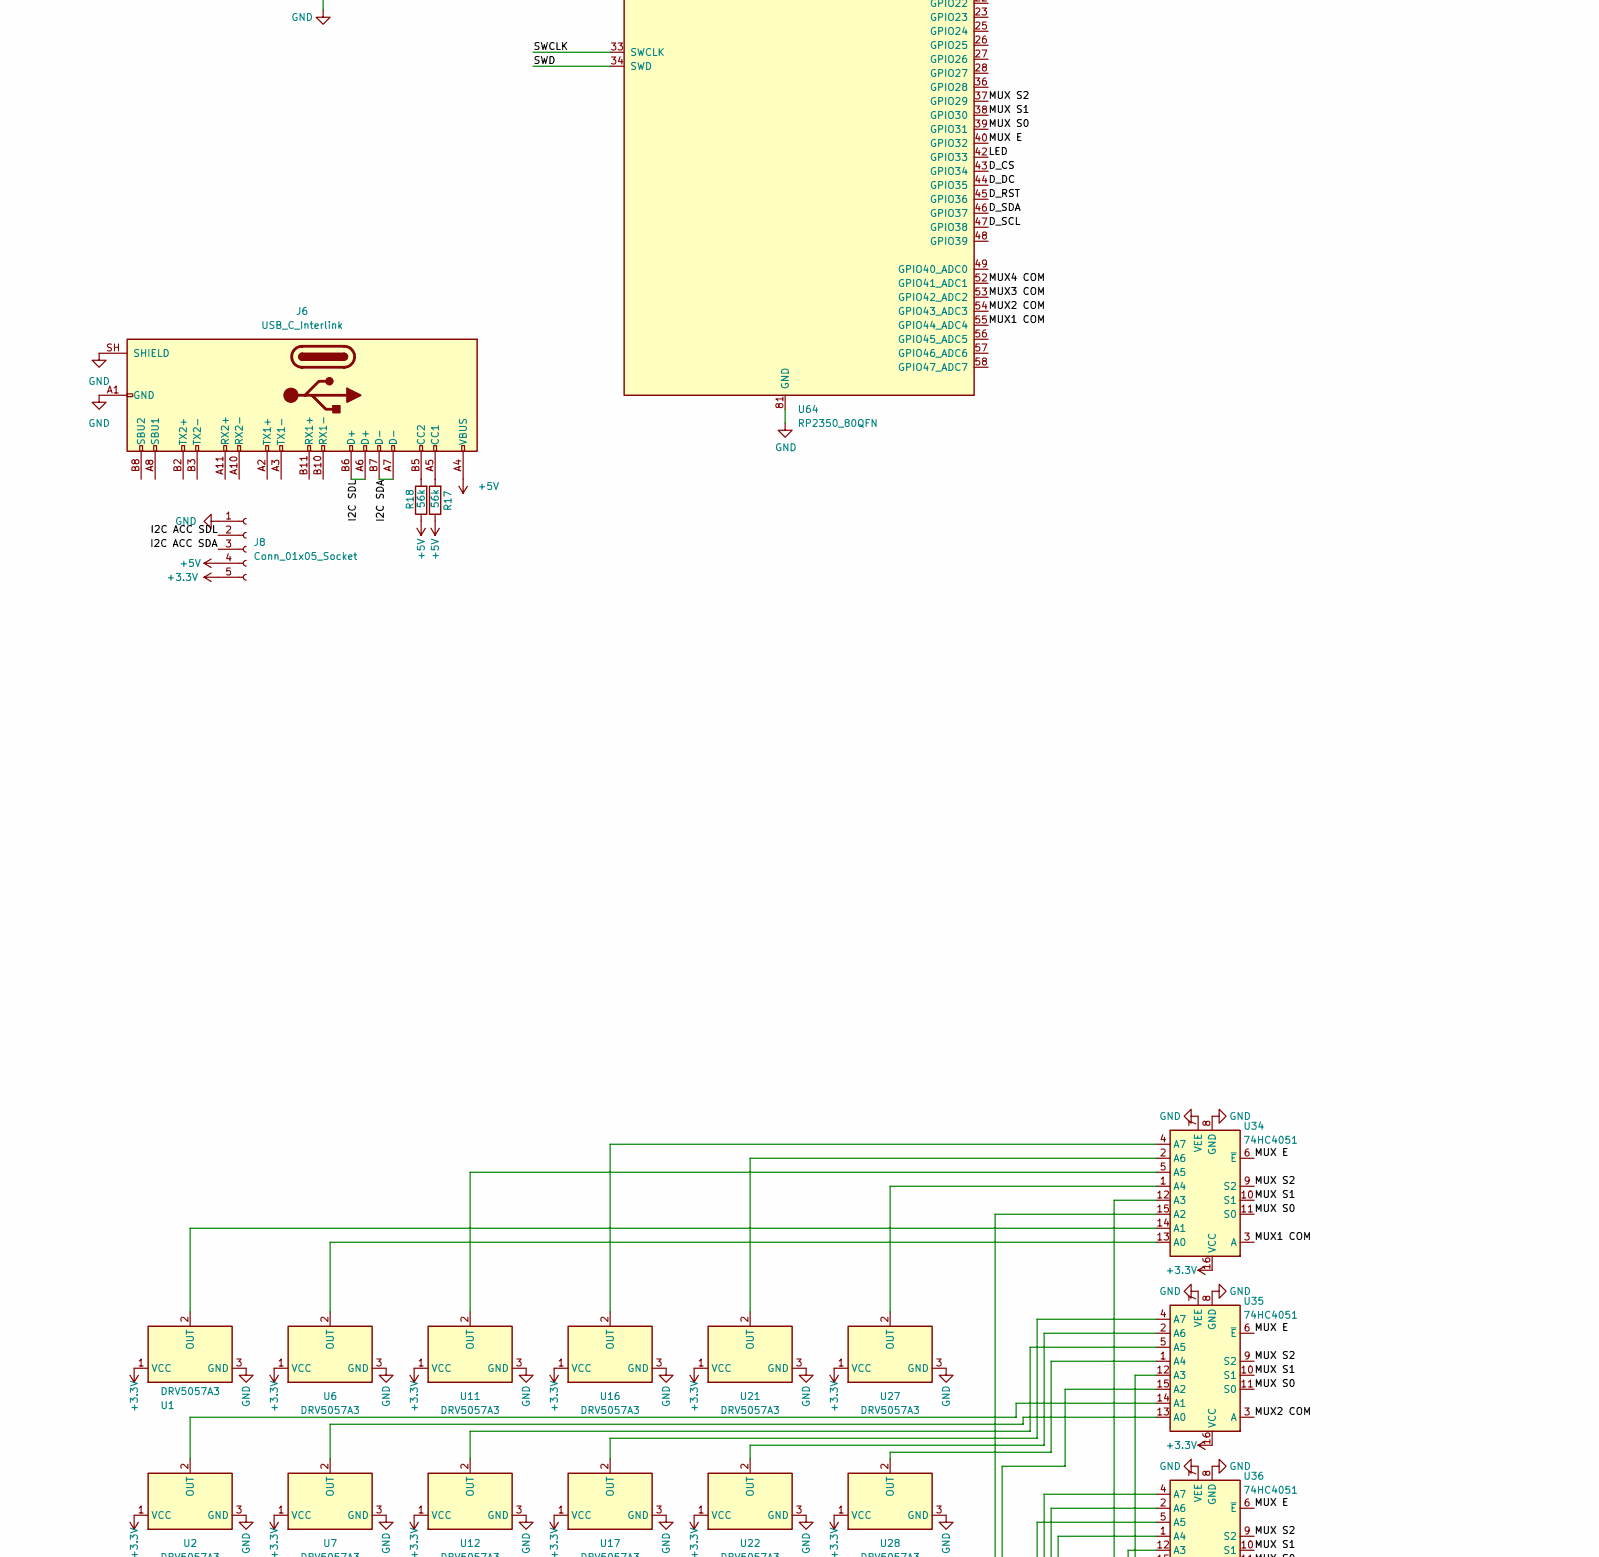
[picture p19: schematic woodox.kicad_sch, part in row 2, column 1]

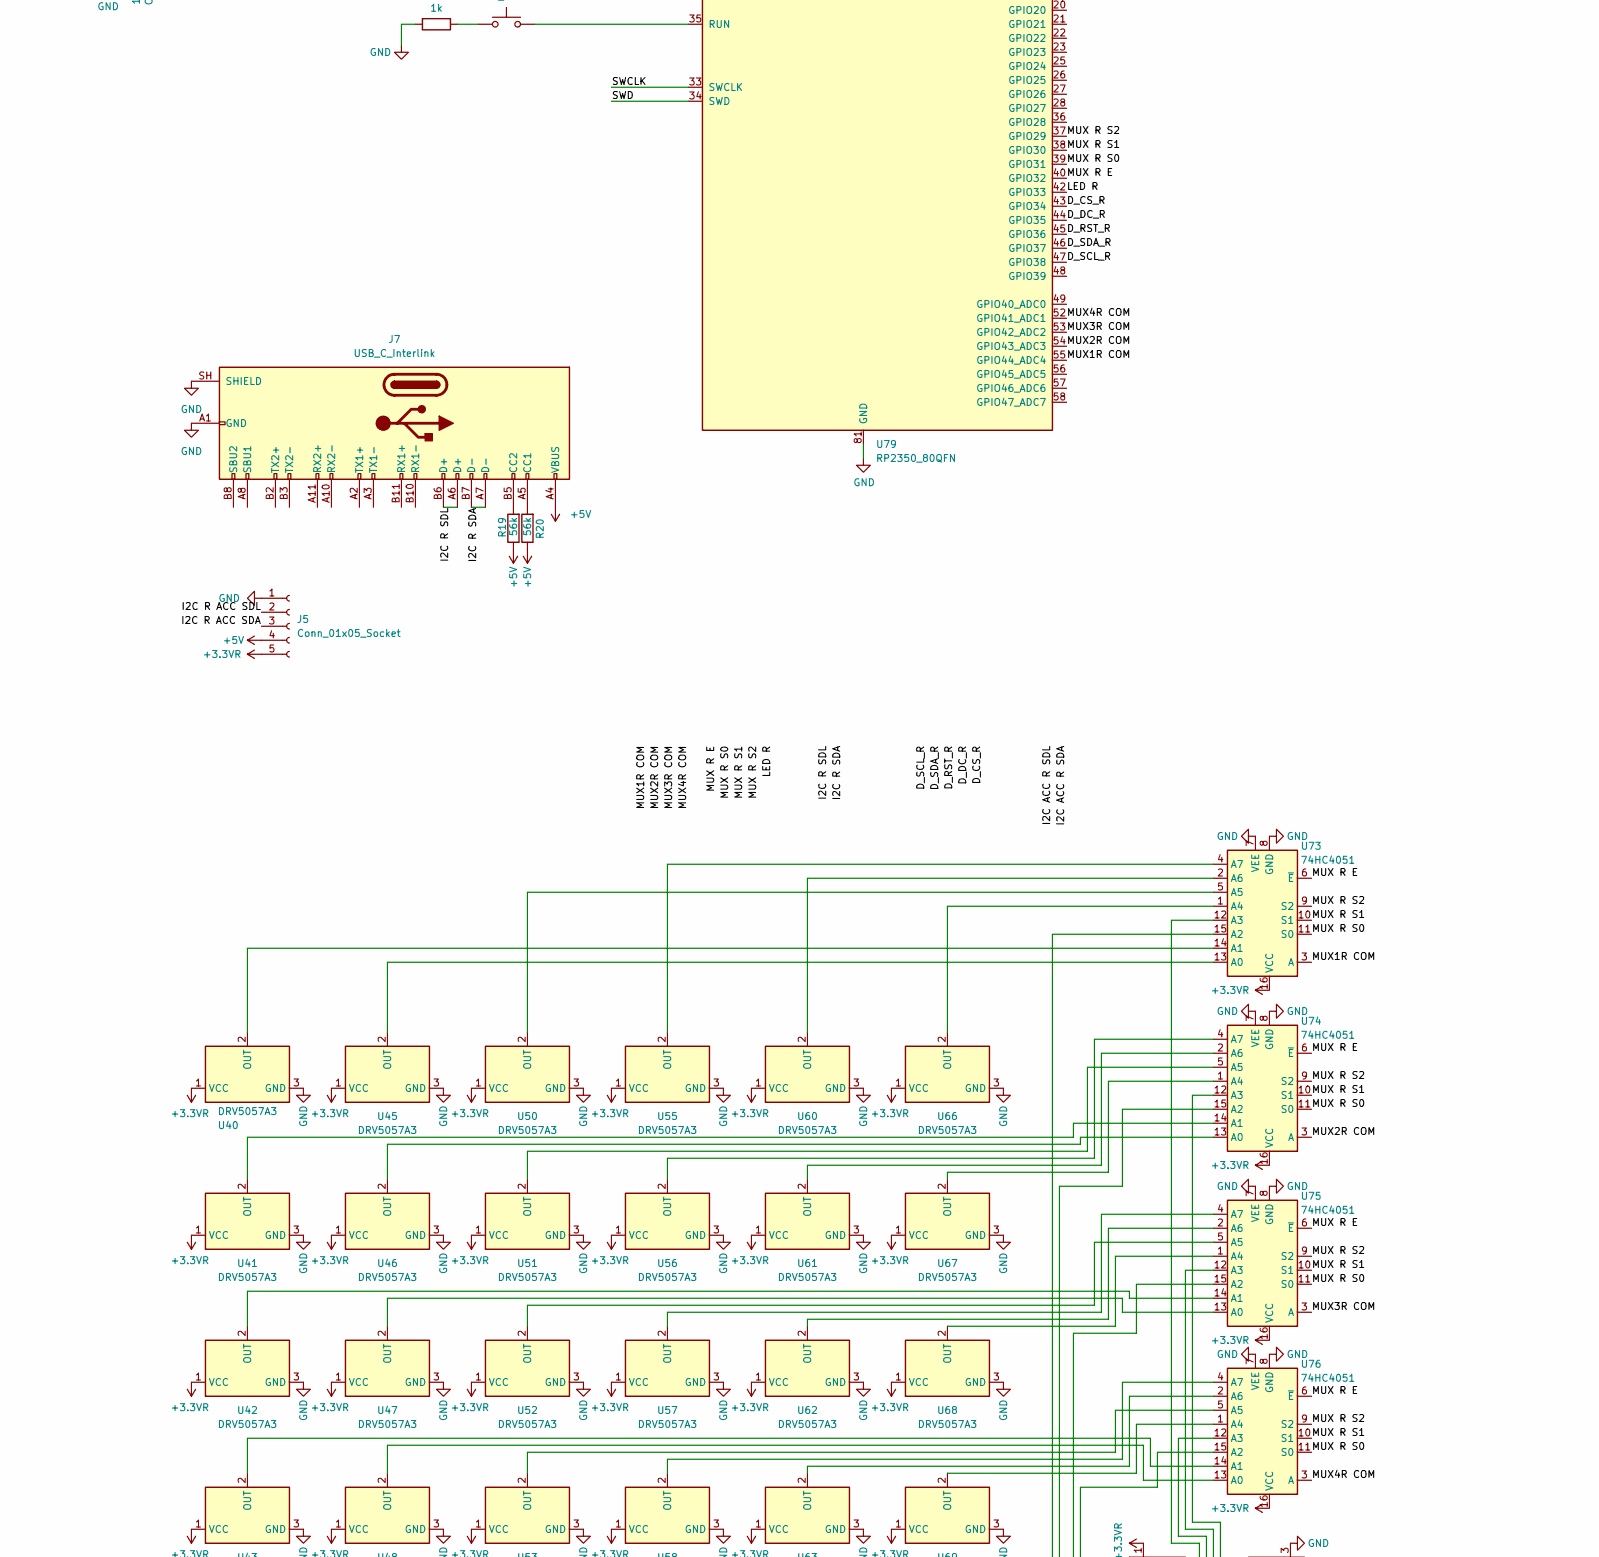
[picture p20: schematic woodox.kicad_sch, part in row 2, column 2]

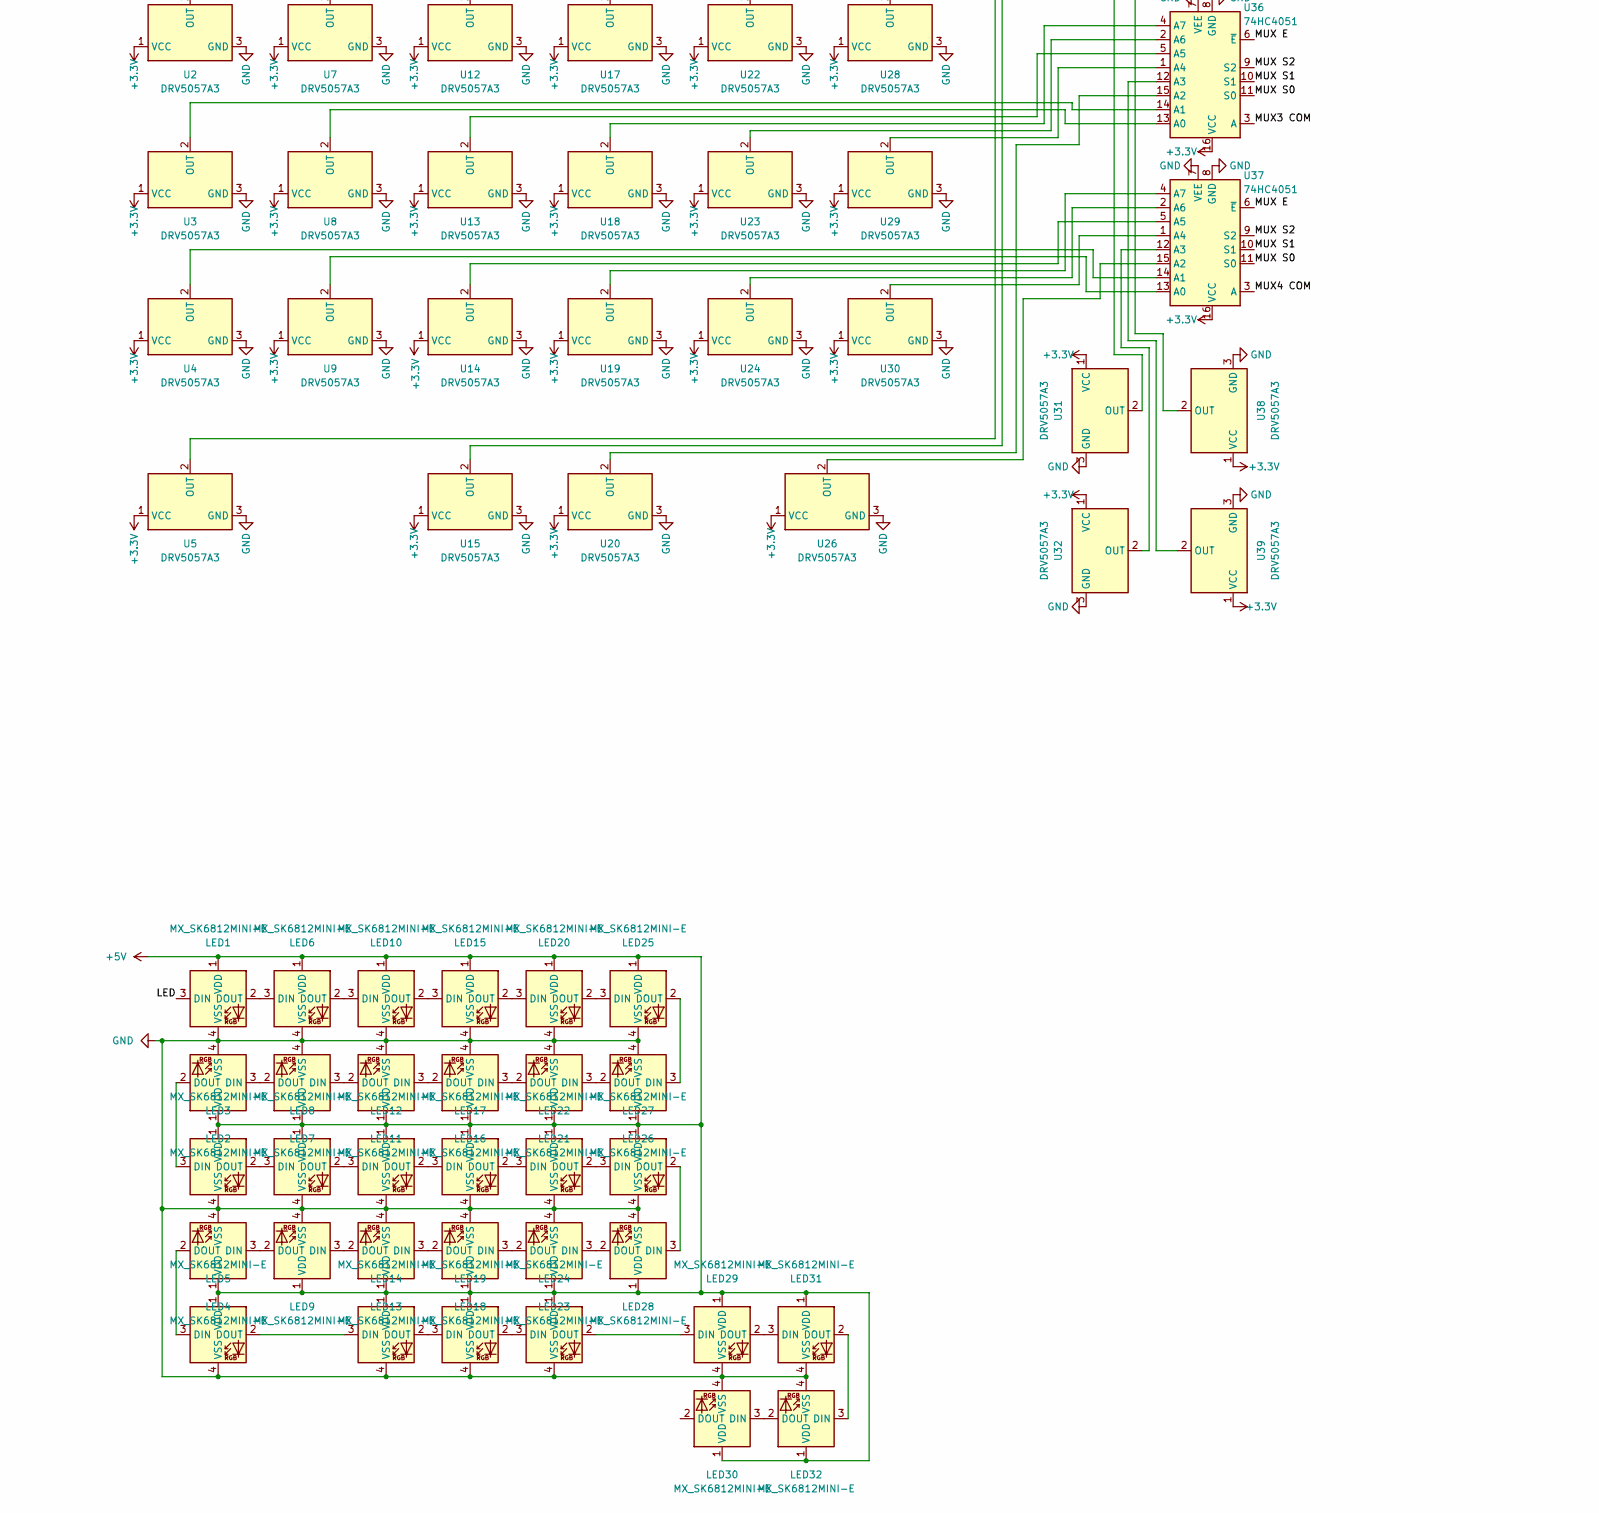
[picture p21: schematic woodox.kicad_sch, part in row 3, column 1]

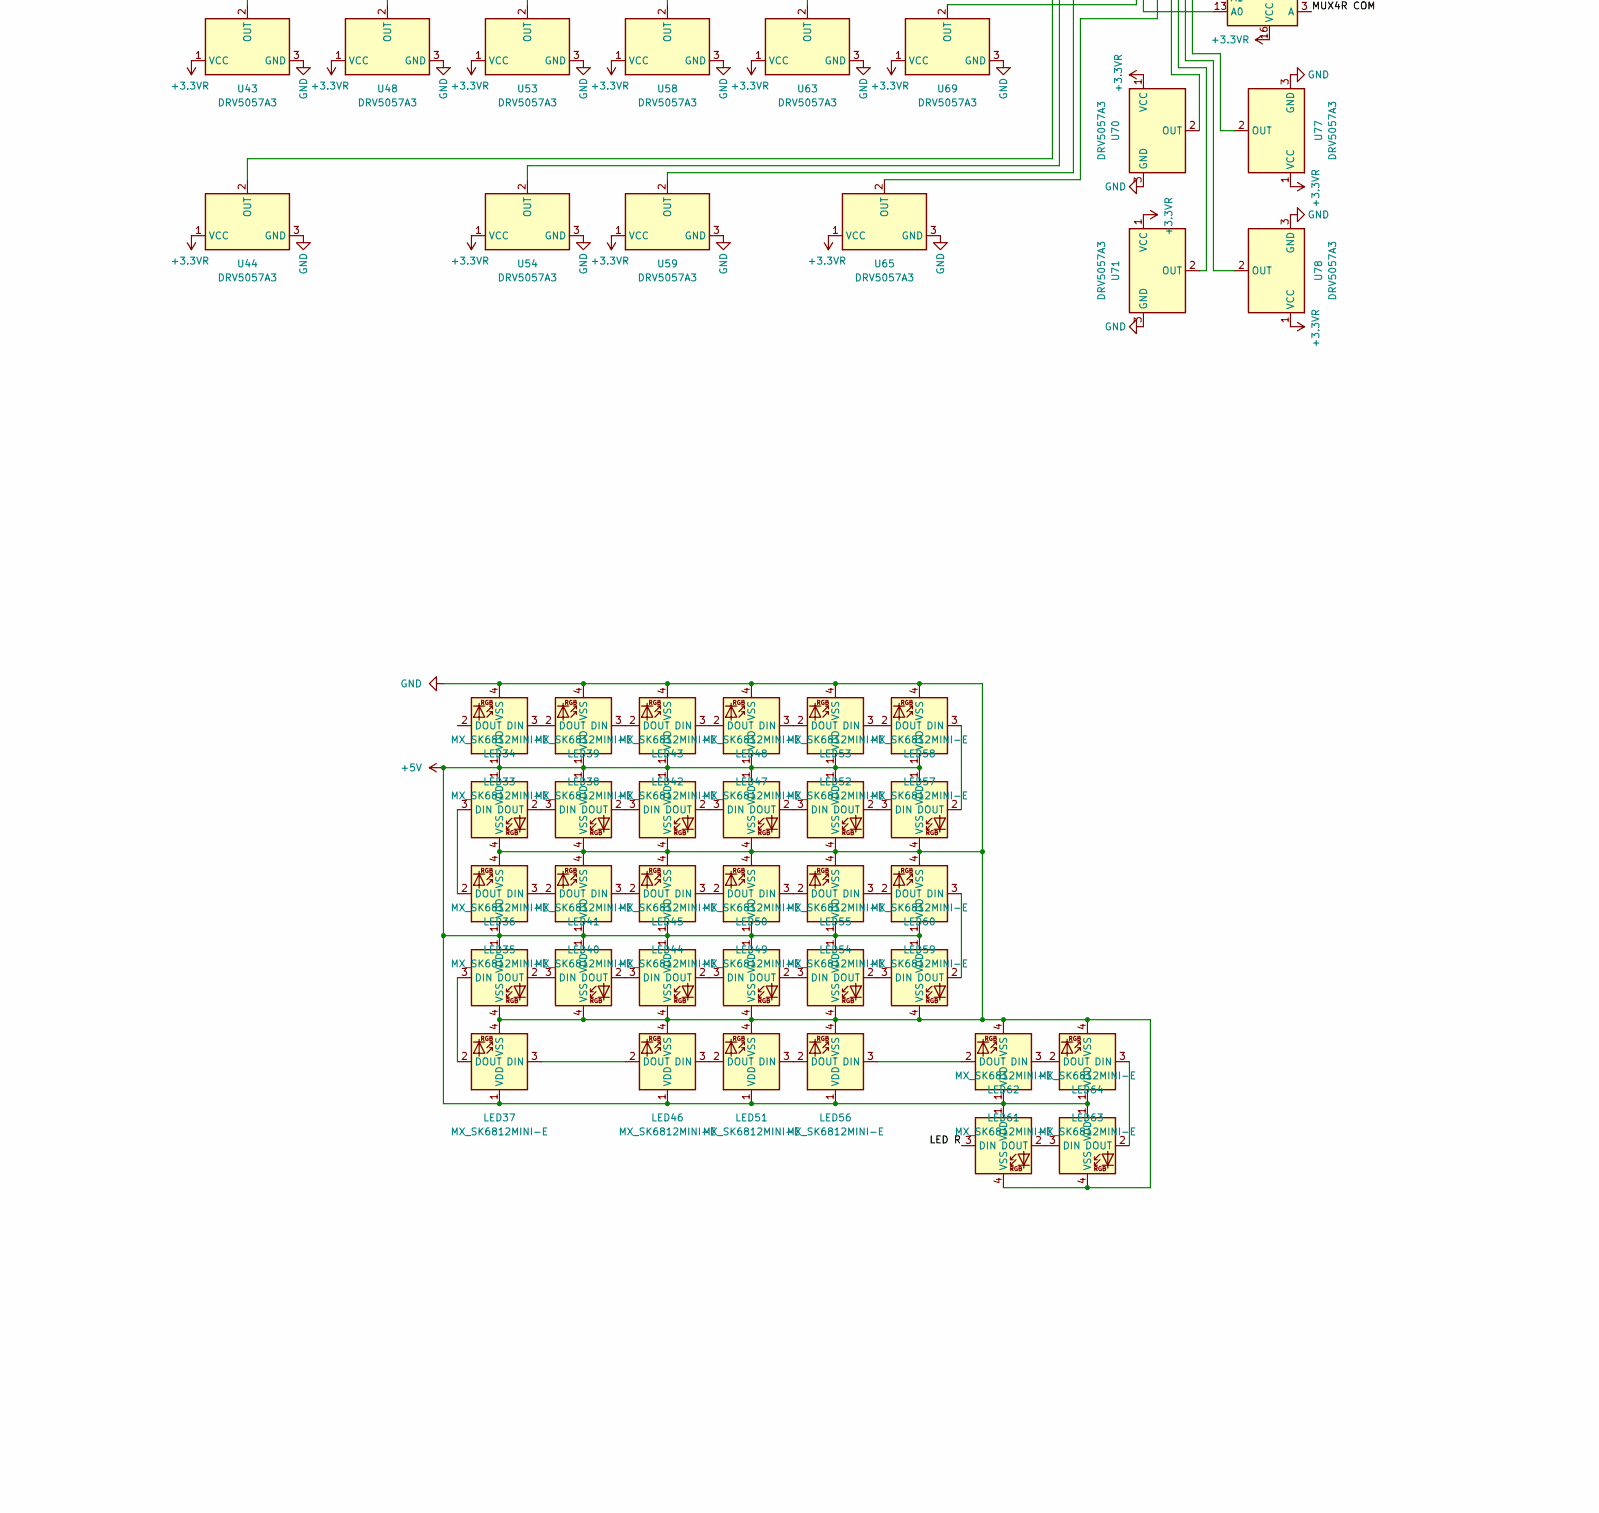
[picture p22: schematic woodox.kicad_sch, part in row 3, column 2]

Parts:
C4, C5, C15, C18, C19, C23, C26, C27, C32, C33, C34, C35, C36, C37, C38, C39, C44, C45, C46, C47, C48, C49, C50, C51: 100n; C_0402_1005Metric
C6, C10, C16, C20: 10uF; C_0402_1005Metric; MPN GRM155R60J106ME15D
C12, C13, C21, C22: 4.7u; C_0402_1005Metric_small_pads
C14, C17, C24, C25: 4.7u; C_0402_1005Metric
C40, C41, C42, C43: 15p; C_0402_1005Metric
J1, J3: Conn_01x03_Female; TestPad_3pins; MPN HEADER
J2, J4: USB_C_To_Host; USB_C_Receptacle_Amphenol_12401610E4-2A; MPN 12401832E402A
J5, J8: Conn_01x05_Socket; TestPad_5pins
J6, J7: USB_C_Interlink; USB_C_Receptacle_Amphenol_12401610E4-2A; MPN 12401832E402A
J9, J10, J11, J12: Conn_01x01; MountingHole_3.2mm_M3_DIN965_Pad
JP1, JP2, JP3, JP4, JP5, JP6, JP7, JP8: SolderJumper_2_Open; SolderJumper-2_P1.3mm_Open_Pad1.0x1.5mm
L2, L3: 3.3u; L_pol_2016; MPN AOTA-B201610S3R3-101-T
LED1, LED2, LED3, LED4, LED5, LED6, LED7, LED8, LED9, LED10, LED11, LED12, LED13, LED14, LED15, LED16, LED17, LED18, LED19, LED20, LED21, LED22, LED23, LED24, LED25, LED26, LED27, LED28, LED29, LED30, LED31, LED32, LED33, LED34, LED35, LED36, LED37, LED38, LED39, LED40, LED41, LED42, LED43, LED44, LED45, LED46, LED47, LED48, LED49, LED50, LED51, LED52, LED53, LED54, LED55, LED56, LED57, LED58, LED59, LED60, LED61, LED62, LED63, LED64: MX_SK6812MINI-E; LED_MX_SK6812MINI-R; MPN SK6812MINI-E
R1, R2, R12, R16, R21, R23: 1k; R_0402_1005Metric
R6, R7, R14, R15: 5k1; R_0402_1005Metric; MPN ERJ-3EKF5101V
R11, R13: DNF; R_0402_1005Metric; MPN ERJ-3EKF1002V; not fitted
R17, R18, R19, R20: 56k; R_0402_1005Metric; MPN ERJ-3EKF1002V
R22, R26: 33; R_0402_1005Metric
R24, R25, R27, R28: 27; R_0402_1005Metric
SW1, SW2, SW3, SW4: SW_Push; SW_Push_1P1T_NO_Vertical_Wuerth_434133025816
U1, U2, U3, U4, U5, U6, U7, U8, U9, U11, U12, U13, U14, U15, U16, U17, U18, U19, U20, U21, U22, U23, U24, U26, U27, U28, U29, U30, U31, U32, U38, U39, U40, U41, U42, U43, U44, U45, U46, U47, U48, U50, U51, U52, U53, U54, U55, U56, U57, U58, U59, U60, U61, U62, U63, U65, U66, U67, U68, U69, U70, U71, U77, U78: DRV5057A3; DRV505x; MPN DRV5057A3
U10: OLED_256x64_I2C; MPN HEADER
U25, U49: W25Q128JVP; WSON-8-1EP_6x5mm_P1.27mm_EP3.4x4.3mm
U33, U72: NCP1117-3.3_SOT223; SOT-223-3_TabPin2; MPN NCP1117LPST33T3G
U34, U35, U36, U37, U73, U74, U75, U76: 74HC4051; TSSOP-16_4.4x5mm_P0.65mm; MPN CD74HC4051PWR
U64, U79: RP2350_80QFN; RP2350-QFN-80-1EP_10x10_P0.4mm_EP3.4x3.4mm_ThermalVias
Y2, Y3: ABM8-272-T3; Crystal_SMD_3225-4Pin_3.2x2.5mm

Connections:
+1V1: C13.1, C15.1, C17.1, C22.1, C23.1, C25.1, C39.1, C44.1, L2.1, L3.1, U64.10 (DVDD), U64.32 (DVDD), U64.51 (DVDD), U64.65 (VREG_FB), U79.10 (DVDD), U79.32 (DVDD), U79.51 (DVDD), U79.65 (VREG_FB)
+3.3V: C4.1, C10.1, C12.1, C18.1, C19.1, C32.1, C33.1, C34.1, C35.1, C36.1, C37.1, C38.1, J8.5, JP2.2 (B), JP7.2 (B), R11.2, R22.1, U1.1 (VCC), U2.1 (VCC), U3.1 (VCC), U4.1 (VCC), U5.1 (VCC), U6.1 (VCC), U7.1 (VCC), U8.1 (VCC), U9.1 (VCC), U11.1 (VCC), U12.1 (VCC), U13.1 (VCC), U14.1 (VCC), U15.1 (VCC), U16.1 (VCC), U17.1 (VCC), U18.1 (VCC), U19.1 (VCC), U20.1 (VCC), U21.1 (VCC), U22.1 (VCC), U23.1 (VCC), U24.1 (VCC), U25.8 (VCC), U26.1 (VCC), U27.1 (VCC), U28.1 (VCC), U29.1 (VCC), U30.1 (VCC), U31.1 (VCC), U32.1 (VCC), U33.2 (VO), U34.16 (VCC), U35.16 (VCC), U36.16 (VCC), U37.16 (VCC), U38.1 (VCC), U39.1 (VCC), U64.5 (IOVDD), U64.15 (IOVDD), U64.24 (IOVDD), U64.29 (IOVDD), U64.41 (IOVDD), U64.50 (IOVDD), U64.59 (ADC_AVDD), U64.60 (IOVDD), U64.64 (VREG_VIN), U64.68 (USB_OTP_VDD), U64.69 (QSPI_IOVDD), U64.76 (IOVDD)
+3.3VR: C5.1, C20.1, C21.1, C26.1, C27.1, C45.1, C46.1, C47.1, C48.1, C49.1, C50.1, C51.1, J5.5, JP3.2 (B), JP6.2 (B), R13.2, R26.1, U40.1 (VCC), U41.1 (VCC), U42.1 (VCC), U43.1 (VCC), U44.1 (VCC), U45.1 (VCC), U46.1 (VCC), U47.1 (VCC), U48.1 (VCC), U49.8 (VCC), U50.1 (VCC), U51.1 (VCC), U52.1 (VCC), U53.1 (VCC), U54.1 (VCC), U55.1 (VCC), U56.1 (VCC), U57.1 (VCC), U58.1 (VCC), U59.1 (VCC), U60.1 (VCC), U61.1 (VCC), U62.1 (VCC), U63.1 (VCC), U65.1 (VCC), U66.1 (VCC), U67.1 (VCC), U68.1 (VCC), U69.1 (VCC), U70.1 (VCC), U71.1 (VCC), U72.2 (VO), U73.16 (VCC), U74.16 (VCC), U75.16 (VCC), U76.16 (VCC), U77.1 (VCC), U78.1 (VCC), U79.5 (IOVDD), U79.15 (IOVDD), U79.24 (IOVDD), U79.29 (IOVDD), U79.41 (IOVDD), U79.50 (IOVDD), U79.59 (ADC_AVDD), U79.60 (IOVDD), U79.64 (VREG_VIN), U79.68 (USB_OTP_VDD), U79.69 (QSPI_IOVDD), U79.76 (IOVDD)
+5V: C6.1, C16.1, J2.A4 (VBUS), J2.A9 (VBUS), J2.B4 (VBUS), J2.B9 (VBUS), J4.A4 (VBUS), J4.A9 (VBUS), J4.B4 (VBUS), J4.B9 (VBUS), J5.4, J6.A4 (VBUS), J6.A9 (VBUS), J6.B4 (VBUS), J6.B9 (VBUS), J7.A4 (VBUS), J7.A9 (VBUS), J7.B4 (VBUS), J7.B9 (VBUS), J8.4, LED1.1 (VDD), LED2.1 (VDD), LED3.1 (VDD), LED4.1 (VDD), LED5.1 (VDD), LED6.1 (VDD), LED7.1 (VDD), LED8.1 (VDD), LED9.1 (VDD), LED10.1 (VDD), LED11.1 (VDD), LED12.1 (VDD), LED13.1 (VDD), LED14.1 (VDD), LED15.1 (VDD), LED16.1 (VDD), LED17.1 (VDD), LED18.1 (VDD), LED19.1 (VDD), LED20.1 (VDD), LED21.1 (VDD), LED22.1 (VDD), LED23.1 (VDD), LED24.1 (VDD), LED25.1 (VDD), LED26.1 (VDD), LED27.1 (VDD), LED28.1 (VDD), LED29.1 (VDD), LED30.1 (VDD), LED31.1 (VDD), LED32.1 (VDD), LED33.1 (VDD), LED34.1 (VDD), LED35.1 (VDD), LED36.1 (VDD), LED37.1 (VDD), LED38.1 (VDD), LED39.1 (VDD), LED40.1 (VDD), LED41.1 (VDD), LED42.1 (VDD), LED43.1 (VDD), LED44.1 (VDD), LED45.1 (VDD), LED46.1 (VDD), LED47.1 (VDD), LED48.1 (VDD), LED49.1 (VDD), LED50.1 (VDD), LED51.1 (VDD), LED52.1 (VDD), LED53.1 (VDD), LED54.1 (VDD), LED55.1 (VDD), LED56.1 (VDD), LED57.1 (VDD), LED58.1 (VDD), LED59.1 (VDD), LED60.1 (VDD), LED61.1 (VDD), LED62.1 (VDD), LED63.1 (VDD), LED64.1 (VDD), R17.1, R18.1, R19.1, R20.1, U33.3 (VI), U72.3 (VI)
/D_CS: JP4.1 (A), U10.7 (CS), U64.43 (GPIO34)
/D_CS_R: JP1.1 (A), U10.1 (GND), U79.43 (GPIO34)
/D_DC: JP3.1 (A), U10.6 (DC), U64.44 (GPIO35)
/D_DC_R: JP2.1 (A), U10.2 (VCC), U79.44 (GPIO35)
/D_RST: U10.5 (RST), U64.45 (GPIO36), U79.47 (GPIO38)
/D_RST_R: U10.3 (SCL), U64.47 (GPIO38), U79.45 (GPIO36)
/D_SDA: U10.4 (SDA), U64.46 (GPIO37), U79.46 (GPIO37)
/I2C ACC SDA: J8.3, U64.3 (GPIO6)
/I2C ACC SDL: J8.2, U64.4 (GPIO7)
/I2C R ACC SDA: J5.3, U79.3 (GPIO6)
/I2C R ACC SDL: J5.2, U79.4 (GPIO7)
/I2C R SDA: J7.A7 (D-), J7.B7 (D-), U79.1 (GPIO4)
/I2C R SDL: J7.A6 (D+), J7.B6 (D+), U79.2 (GPIO5)
/I2C SDA: J6.A7 (D-), J6.B7 (D-), U64.1 (GPIO4)
/I2C SDL: J6.A6 (D+), J6.B6 (D+), U64.2 (GPIO5)
/LED: LED1.3 (DIN), U64.42 (GPIO33)
/LED R: LED62.3 (DIN), U79.42 (GPIO33)
/MUX1 COM: U34.3 (A), U64.55 (GPIO44_ADC4)
/MUX1R COM: U73.3 (A), U79.55 (GPIO44_ADC4)
/MUX2 COM: U35.3 (A), U64.54 (GPIO43_ADC3)
/MUX2R COM: U74.3 (A), U79.54 (GPIO43_ADC3)
/MUX3 COM: U36.3 (A), U64.53 (GPIO42_ADC2)
/MUX3R COM: U75.3 (A), U79.53 (GPIO42_ADC2)
/MUX4 COM: U37.3 (A), U64.52 (GPIO41_ADC1)
/MUX4R COM: U76.3 (A), U79.52 (GPIO41_ADC1)
/MUX E: U34.6 (~E), U35.6 (~E), U36.6 (~E), U37.6 (~E), U64.40 (GPIO32)
/MUX R E: U73.6 (~E), U74.6 (~E), U75.6 (~E), U76.6 (~E), U79.40 (GPIO32)
/MUX R S0: U73.11 (S0), U74.11 (S0), U75.11 (S0), U76.11 (S0), U79.39 (GPIO31)
/MUX R S1: U73.10 (S1), U74.10 (S1), U75.10 (S1), U76.10 (S1), U79.38 (GPIO30)
/MUX R S2: U73.9 (S2), U74.9 (S2), U75.9 (S2), U76.9 (S2), U79.37 (GPIO29)
/MUX S0: U34.11 (S0), U35.11 (S0), U36.11 (S0), U37.11 (S0), U64.39 (GPIO31)
/MUX S1: U34.10 (S1), U35.10 (S1), U36.10 (S1), U37.10 (S1), U64.38 (GPIO30)
/MUX S2: U34.9 (S2), U35.9 (S2), U36.9 (S2), U37.9 (S2), U64.37 (GPIO29)
/QSPI_R_SCLK: U49.6 (CLK), U79.71 (QSPI_SCLK)
/QSPI_R_SD0: U49.5 (DI(IO0)), U79.72 (QSPI_SD0)
/QSPI_R_SD1: U49.2 (DO(IO1)), U79.74 (QSPI_SD1)
/QSPI_R_SD2: U49.3 (IO2), U79.73 (QSPI_SD2)
/QSPI_R_SD3: U49.7 (IO3), U79.70 (QSPI_SD3)
/QSPI_R_SS: R2.1, R13.1, U49.1 (~CS), U79.75 (QSPI_SS)
/QSPI_SCLK: U25.6 (CLK), U64.71 (QSPI_SCLK)
/QSPI_SD0: U25.5 (DI(IO0)), U64.72 (QSPI_SD0)
/QSPI_SD1: U25.2 (DO(IO1)), U64.74 (QSPI_SD1)
/QSPI_SD2: U25.3 (IO2), U64.73 (QSPI_SD2)
/QSPI_SD3: U25.7 (IO3), U64.70 (QSPI_SD3)
/QSPI_SS: R1.1, R11.1, U25.1 (~CS), U64.75 (QSPI_SS)
/RUN: SW2.2, U64.35 (RUN)
/SWCLK: J1.3, J3.3, U64.33 (SWCLK), U79.33 (SWCLK)
/SWD: J1.2, J3.2, U64.34 (SWD), U79.34 (SWD)
/USB_D+: J2.A6 (D+), J2.B6 (D+), J4.A6 (D+), J4.B6 (D+), R24.1, R27.1
/USB_D-: J2.A7 (D-), J2.B7 (D-), J4.A7 (D-), J4.B7 (D-), R25.1, R28.1
/VREG_AVDD: C14.1, R22.2, U64.61 (VREG_AVDD)
/VREG_AVDD_R: C24.1, R26.2, U79.61 (VREG_AVDD)
/VREG_LX: L2.2, U64.63 (VREG_LX)
/VREG_LX_R: L3.2, U79.63 (VREG_LX)
/~USB_BOOT_R: R2.2, SW3.2
/~USB_BOOT: R1.2, SW1.2
GND: C4.2, C5.2, C6.2, C10.2, C12.2, C13.2, C14.2, C15.2, C16.2, C17.2, C18.2, C19.2, C20.2, C21.2, C22.2, C23.2, C24.2, C25.2, C26.2, C27.2, C32.2, C33.2, C34.2, C35.2, C36.2, C37.2, C38.2, C39.2, C40.2, C41.2, C42.2, C43.2, C44.2, C45.2, C46.2, C47.2, C48.2, C49.2, C50.2, C51.2, J1.1, J2.A1 (GND), J2.A12 (GND), J2.B1 (GND), J2.B12 (GND), J2.SH (SHIELD), J3.1, J4.A1 (GND), J4.A12 (GND), J4.B1 (GND), J4.B12 (GND), J4.SH (SHIELD), J5.1, J6.A1 (GND), J6.A12 (GND), J6.B1 (GND), J6.B12 (GND), J6.SH (SHIELD), J7.A1 (GND), J7.A12 (GND), J7.B1 (GND), J7.B12 (GND), J7.SH (SHIELD), J8.1, J9.1 (Pin_1_1), J10.1 (Pin_1_1), J11.1 (Pin_1_1), J12.1 (Pin_1_1), JP1.2 (B), JP4.2 (B), JP5.2 (B), JP8.2 (B), LED1.4 (VSS), LED2.4 (VSS), LED3.4 (VSS), LED4.4 (VSS), LED5.4 (VSS), LED6.4 (VSS), LED7.4 (VSS), LED8.4 (VSS), LED9.4 (VSS), LED10.4 (VSS), LED11.4 (VSS), LED12.4 (VSS), LED13.4 (VSS), LED14.4 (VSS), LED15.4 (VSS), LED16.4 (VSS), LED17.4 (VSS), LED18.4 (VSS), LED19.4 (VSS), LED20.4 (VSS), LED21.4 (VSS), LED22.4 (VSS), LED23.4 (VSS), LED24.4 (VSS), LED25.4 (VSS), LED26.4 (VSS), LED27.4 (VSS), LED28.4 (VSS), LED29.4 (VSS), LED30.4 (VSS), LED31.4 (VSS), LED32.4 (VSS), LED33.4 (VSS), LED34.4 (VSS), LED35.4 (VSS), LED36.4 (VSS), LED37.4 (VSS), LED38.4 (VSS), LED39.4 (VSS), LED40.4 (VSS), LED41.4 (VSS), LED42.4 (VSS), LED43.4 (VSS), LED44.4 (VSS), LED45.4 (VSS), LED46.4 (VSS), LED47.4 (VSS), LED48.4 (VSS), LED49.4 (VSS), LED50.4 (VSS), LED51.4 (VSS), LED52.4 (VSS), LED53.4 (VSS)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
unnamed: C41.1, R12.2, Y2.3
unnamed: C43.1, R21.2, Y3.3
unnamed: J2.A5 (CC1), R7.1
unnamed: J2.B5 (CC2), R6.1
unnamed: J4.A5 (CC1), R15.1
unnamed: J4.B5 (CC2), R14.1
unnamed: J6.A5 (CC1), R17.2
unnamed: J6.B5 (CC2), R18.2
unnamed: J7.A5 (CC1), R20.2
unnamed: J7.B5 (CC2), R19.2
unnamed: JP5.1 (A), JP6.1 (A), U79.6 (GPIO8)
unnamed: JP7.1 (A), JP8.1 (A), U64.6 (GPIO8)
unnamed: LED1.2 (DOUT), LED6.3 (DIN)
unnamed: LED2.3 (DIN), LED7.2 (DOUT)
unnamed: LED2.2 (DOUT), LED3.3 (DIN)
unnamed: LED3.2 (DOUT), LED8.3 (DIN)
unnamed: LED4.3 (DIN), LED9.2 (DOUT)
unnamed: LED4.2 (DOUT), LED5.3 (DIN)
unnamed: LED6.2 (DOUT), LED10.3 (DIN)
unnamed: LED10.2 (DOUT), LED15.3 (DIN)
unnamed: LED11.3 (DIN), LED16.2 (DOUT)
unnamed: LED7.3 (DIN), LED11.2 (DOUT)
unnamed: LED8.2 (DOUT), LED12.3 (DIN)
unnamed: LED12.2 (DOUT), LED17.3 (DIN)
unnamed: LED13.3 (DIN), LED18.2 (DOUT)
unnamed: LED9.3 (DIN), LED13.2 (DOUT)
unnamed: LED5.2 (DOUT), LED14.3 (DIN)
unnamed: LED14.2 (DOUT), LED19.3 (DIN)
unnamed: LED15.2 (DOUT), LED20.3 (DIN)
unnamed: LED16.3 (DIN), LED21.2 (DOUT)
unnamed: LED17.2 (DOUT), LED22.3 (DIN)
unnamed: LED18.3 (DIN), LED23.2 (DOUT)
unnamed: LED19.2 (DOUT), LED24.3 (DIN)
unnamed: LED20.2 (DOUT), LED25.3 (DIN)
unnamed: LED21.3 (DIN), LED26.2 (DOUT)
unnamed: LED22.2 (DOUT), LED27.3 (DIN)
unnamed: LED23.3 (DIN), LED28.2 (DOUT)
unnamed: LED24.2 (DOUT), LED29.3 (DIN)
unnamed: LED25.2 (DOUT), LED26.3 (DIN)
unnamed: LED27.2 (DOUT), LED28.3 (DIN)
unnamed: LED29.2 (DOUT), LED31.3 (DIN)
unnamed: LED30.3 (DIN), LED32.2 (DOUT)
unnamed: LED31.2 (DOUT), LED32.3 (DIN)
unnamed: LED33.3 (DIN), LED38.2 (DOUT)
unnamed: LED34.3 (DIN), LED35.2 (DOUT)
unnamed: LED34.2 (DOUT), LED39.3 (DIN)
unnamed: LED35.3 (DIN), LED40.2 (DOUT)
unnamed: LED36.3 (DIN), LED37.2 (DOUT)
unnamed: LED36.2 (DOUT), LED41.3 (DIN)
unnamed: LED37.3 (DIN), LED46.2 (DOUT)
unnamed: LED38.3 (DIN), LED42.2 (DOUT)
unnamed: LED39.2 (DOUT), LED43.3 (DIN)
unnamed: LED40.3 (DIN), LED44.2 (DOUT)
unnamed: LED41.2 (DOUT), LED45.3 (DIN)
unnamed: LED42.3 (DIN), LED47.2 (DOUT)
unnamed: LED43.2 (DOUT), LED48.3 (DIN)
unnamed: LED44.3 (DIN), LED49.2 (DOUT)
unnamed: LED45.2 (DOUT), LED50.3 (DIN)
unnamed: LED46.3 (DIN), LED51.2 (DOUT)
unnamed: LED47.3 (DIN), LED52.2 (DOUT)
unnamed: LED48.2 (DOUT), LED53.3 (DIN)
unnamed: LED49.3 (DIN), LED54.2 (DOUT)
unnamed: LED50.2 (DOUT), LED55.3 (DIN)
unnamed: LED51.3 (DIN), LED56.2 (DOUT)
unnamed: LED52.3 (DIN), LED57.2 (DOUT)
unnamed: LED53.2 (DOUT), LED58.3 (DIN)
unnamed: LED54.3 (DIN), LED59.2 (DOUT)
unnamed: LED55.2 (DOUT), LED60.3 (DIN)
unnamed: LED56.3 (DIN), LED61.2 (DOUT)
unnamed: LED57.3 (DIN), LED58.2 (DOUT)
unnamed: LED59.3 (DIN), LED60.2 (DOUT)
unnamed: LED61.3 (DIN), LED63.2 (DOUT)
unnamed: LED62.2 (DOUT), LED64.3 (DIN)
unnamed: LED63.3 (DIN), LED64.2 (DOUT)
unnamed: R16.1, SW2.1
unnamed: R23.1, SW4.1
unnamed: U1.2 (OUT), U34.14 (A1)
unnamed: U2.2 (OUT), U35.14 (A1)
unnamed: U3.2 (OUT), U36.14 (A1)
unnamed: U11.2 (OUT), U34.5 (A5)
unnamed: U12.2 (OUT), U35.5 (A5)
unnamed: U13.2 (OUT), U36.5 (A5)
unnamed: U14.2 (OUT), U37.5 (A5)
unnamed: U15.2 (OUT), U35.15 (A2)
unnamed: U16.2 (OUT), U34.4 (A7)
unnamed: U17.2 (OUT), U35.4 (A7)
unnamed: U18.2 (OUT), U36.4 (A7)
unnamed: U19.2 (OUT), U37.4 (A7)
unnamed: U20.2 (OUT), U36.15 (A2)
unnamed: U21.2 (OUT), U34.2 (A6)
unnamed: U22.2 (OUT), U35.2 (A6)
unnamed: U23.2 (OUT), U36.2 (A6)
unnamed: U24.2 (OUT), U37.2 (A6)
unnamed: U26.2 (OUT), U37.15 (A2)
unnamed: U27.2 (OUT), U34.1 (A4)
unnamed: U28.2 (OUT), U35.1 (A4)
unnamed: U29.2 (OUT), U36.1 (A4)
unnamed: U30.2 (OUT), U37.1 (A4)
unnamed: U31.2 (OUT), U34.12 (A3)
unnamed: U32.2 (OUT), U37.12 (A3)
unnamed: U6.2 (OUT), U34.13 (A0)
unnamed: U5.2 (OUT), U34.15 (A2)
unnamed: U7.2 (OUT), U35.13 (A0)
unnamed: U35.12 (A3), U38.2 (OUT)
unnamed: U8.2 (OUT), U36.13 (A0)
unnamed: U36.12 (A3), U39.2 (OUT)
unnamed: U9.2 (OUT), U37.13 (A0)
unnamed: U4.2 (OUT), U37.14 (A1)
unnamed: U40.2 (OUT), U73.14 (A1)
unnamed: U41.2 (OUT), U74.14 (A1)
unnamed: U42.2 (OUT), U75.14 (A1)
unnamed: U43.2 (OUT), U76.14 (A1)
unnamed: U44.2 (OUT), U73.15 (A2)
unnamed: U45.2 (OUT), U73.13 (A0)
unnamed: U46.2 (OUT), U74.13 (A0)
unnamed: U47.2 (OUT), U75.13 (A0)
unnamed: U48.2 (OUT), U76.13 (A0)
unnamed: U50.2 (OUT), U73.5 (A5)
unnamed: U51.2 (OUT), U74.5 (A5)
unnamed: U52.2 (OUT), U75.5 (A5)
unnamed: U53.2 (OUT), U76.5 (A5)
unnamed: U54.2 (OUT), U74.15 (A2)
unnamed: U55.2 (OUT), U73.4 (A7)
unnamed: U56.2 (OUT), U74.4 (A7)
unnamed: U57.2 (OUT), U75.4 (A7)
unnamed: U58.2 (OUT), U76.4 (A7)
unnamed: U59.2 (OUT), U75.15 (A2)
unnamed: U60.2 (OUT), U73.2 (A6)
unnamed: U61.2 (OUT), U74.2 (A6)
unnamed: U62.2 (OUT), U75.2 (A6)
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

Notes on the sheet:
12MHz Crystal
Primary Flash
Make sure R7 and R8 are close to RP2350

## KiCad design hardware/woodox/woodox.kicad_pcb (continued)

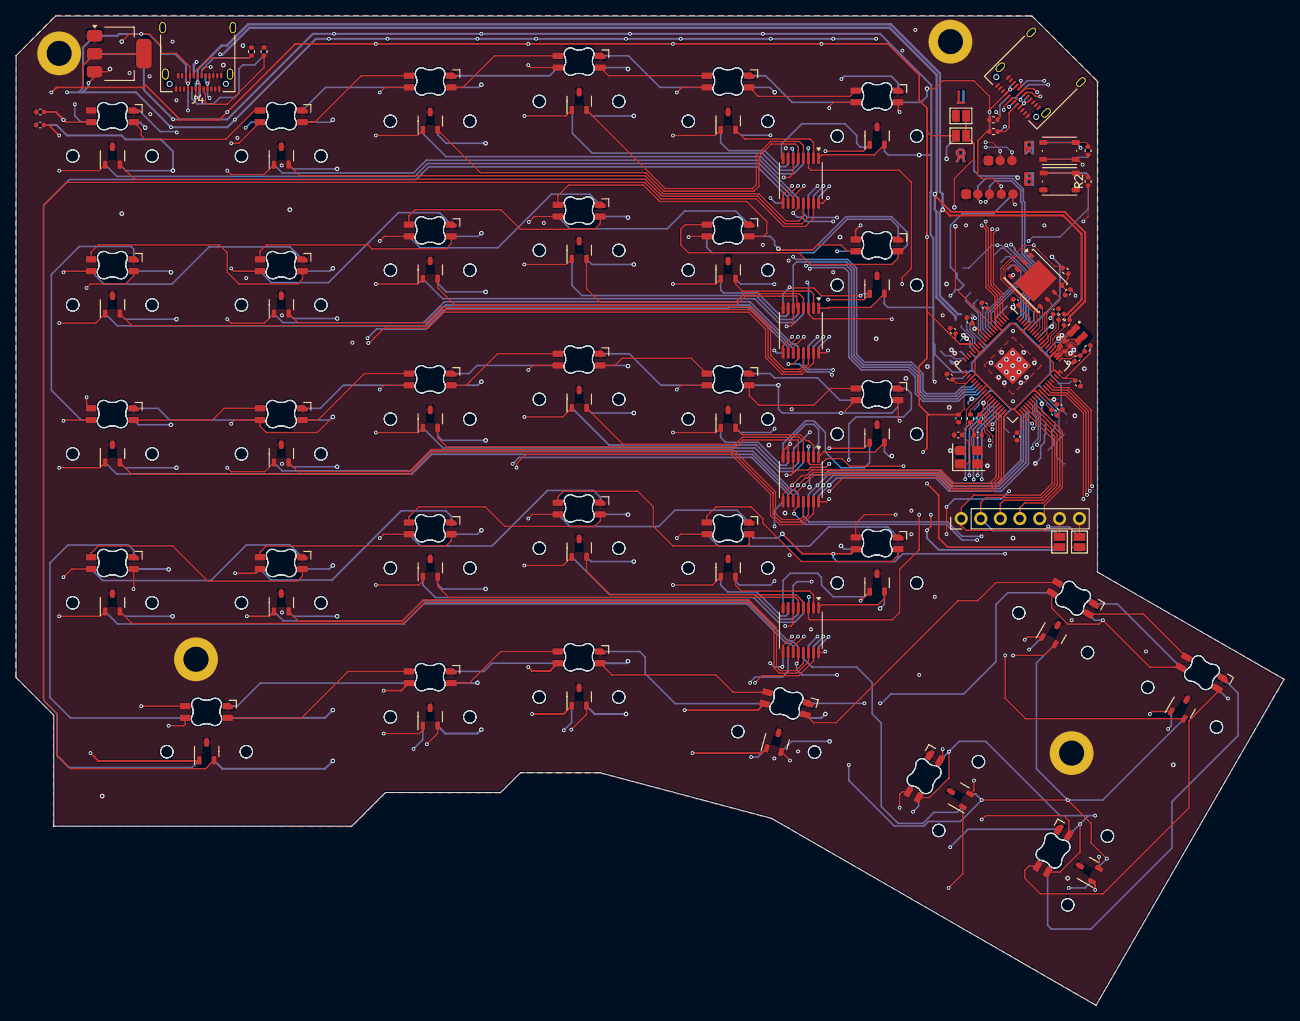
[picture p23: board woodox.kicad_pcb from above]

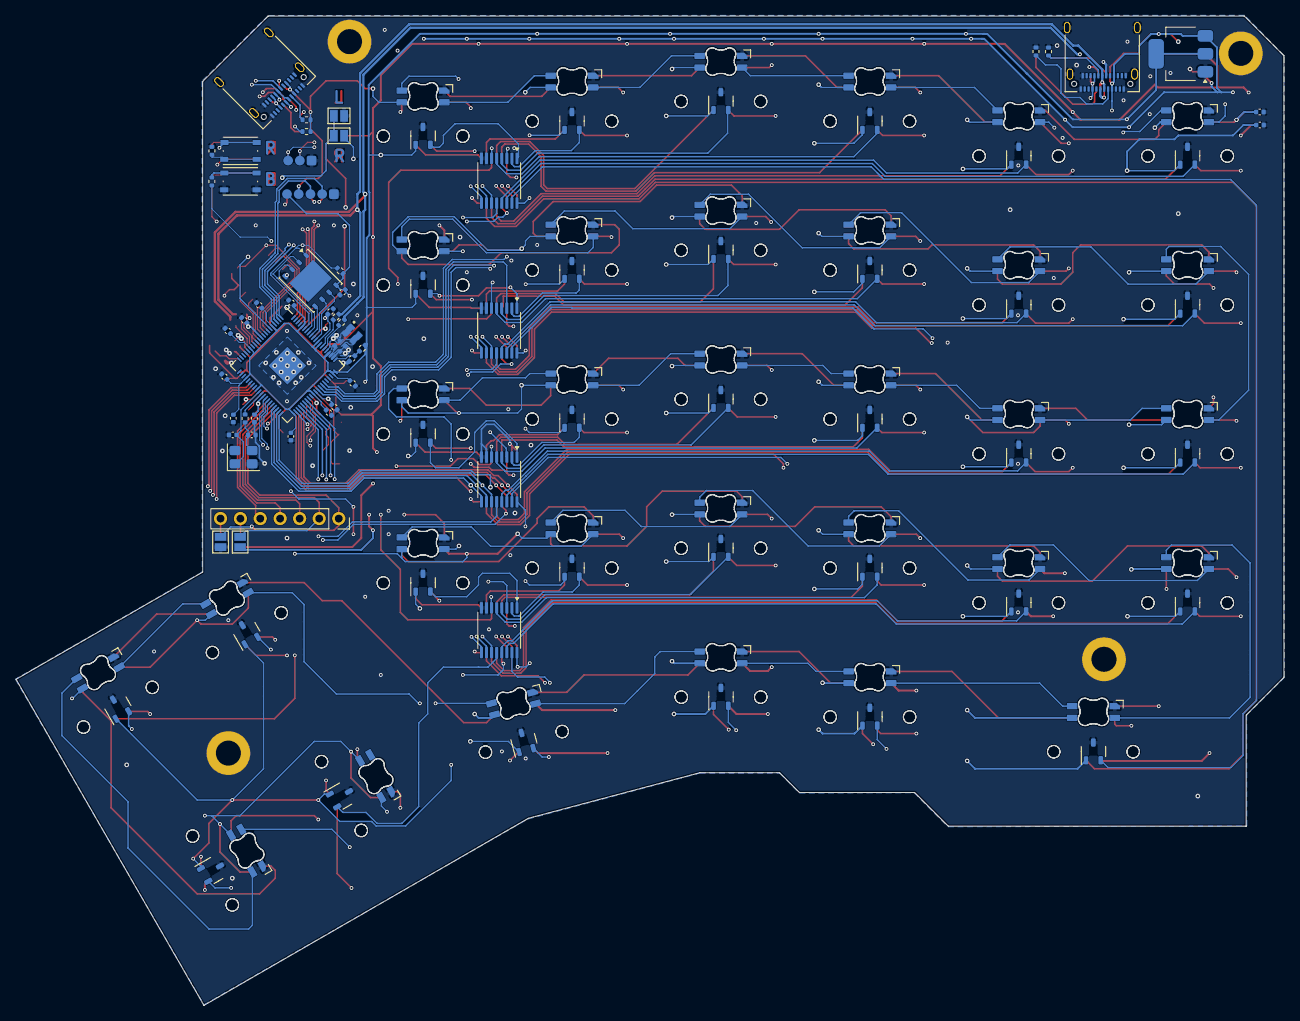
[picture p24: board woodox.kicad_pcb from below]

Board: 4 copper layers, 162.2 x 126.5 mm, 233 parts (114 on the bottom side), 210 nets.

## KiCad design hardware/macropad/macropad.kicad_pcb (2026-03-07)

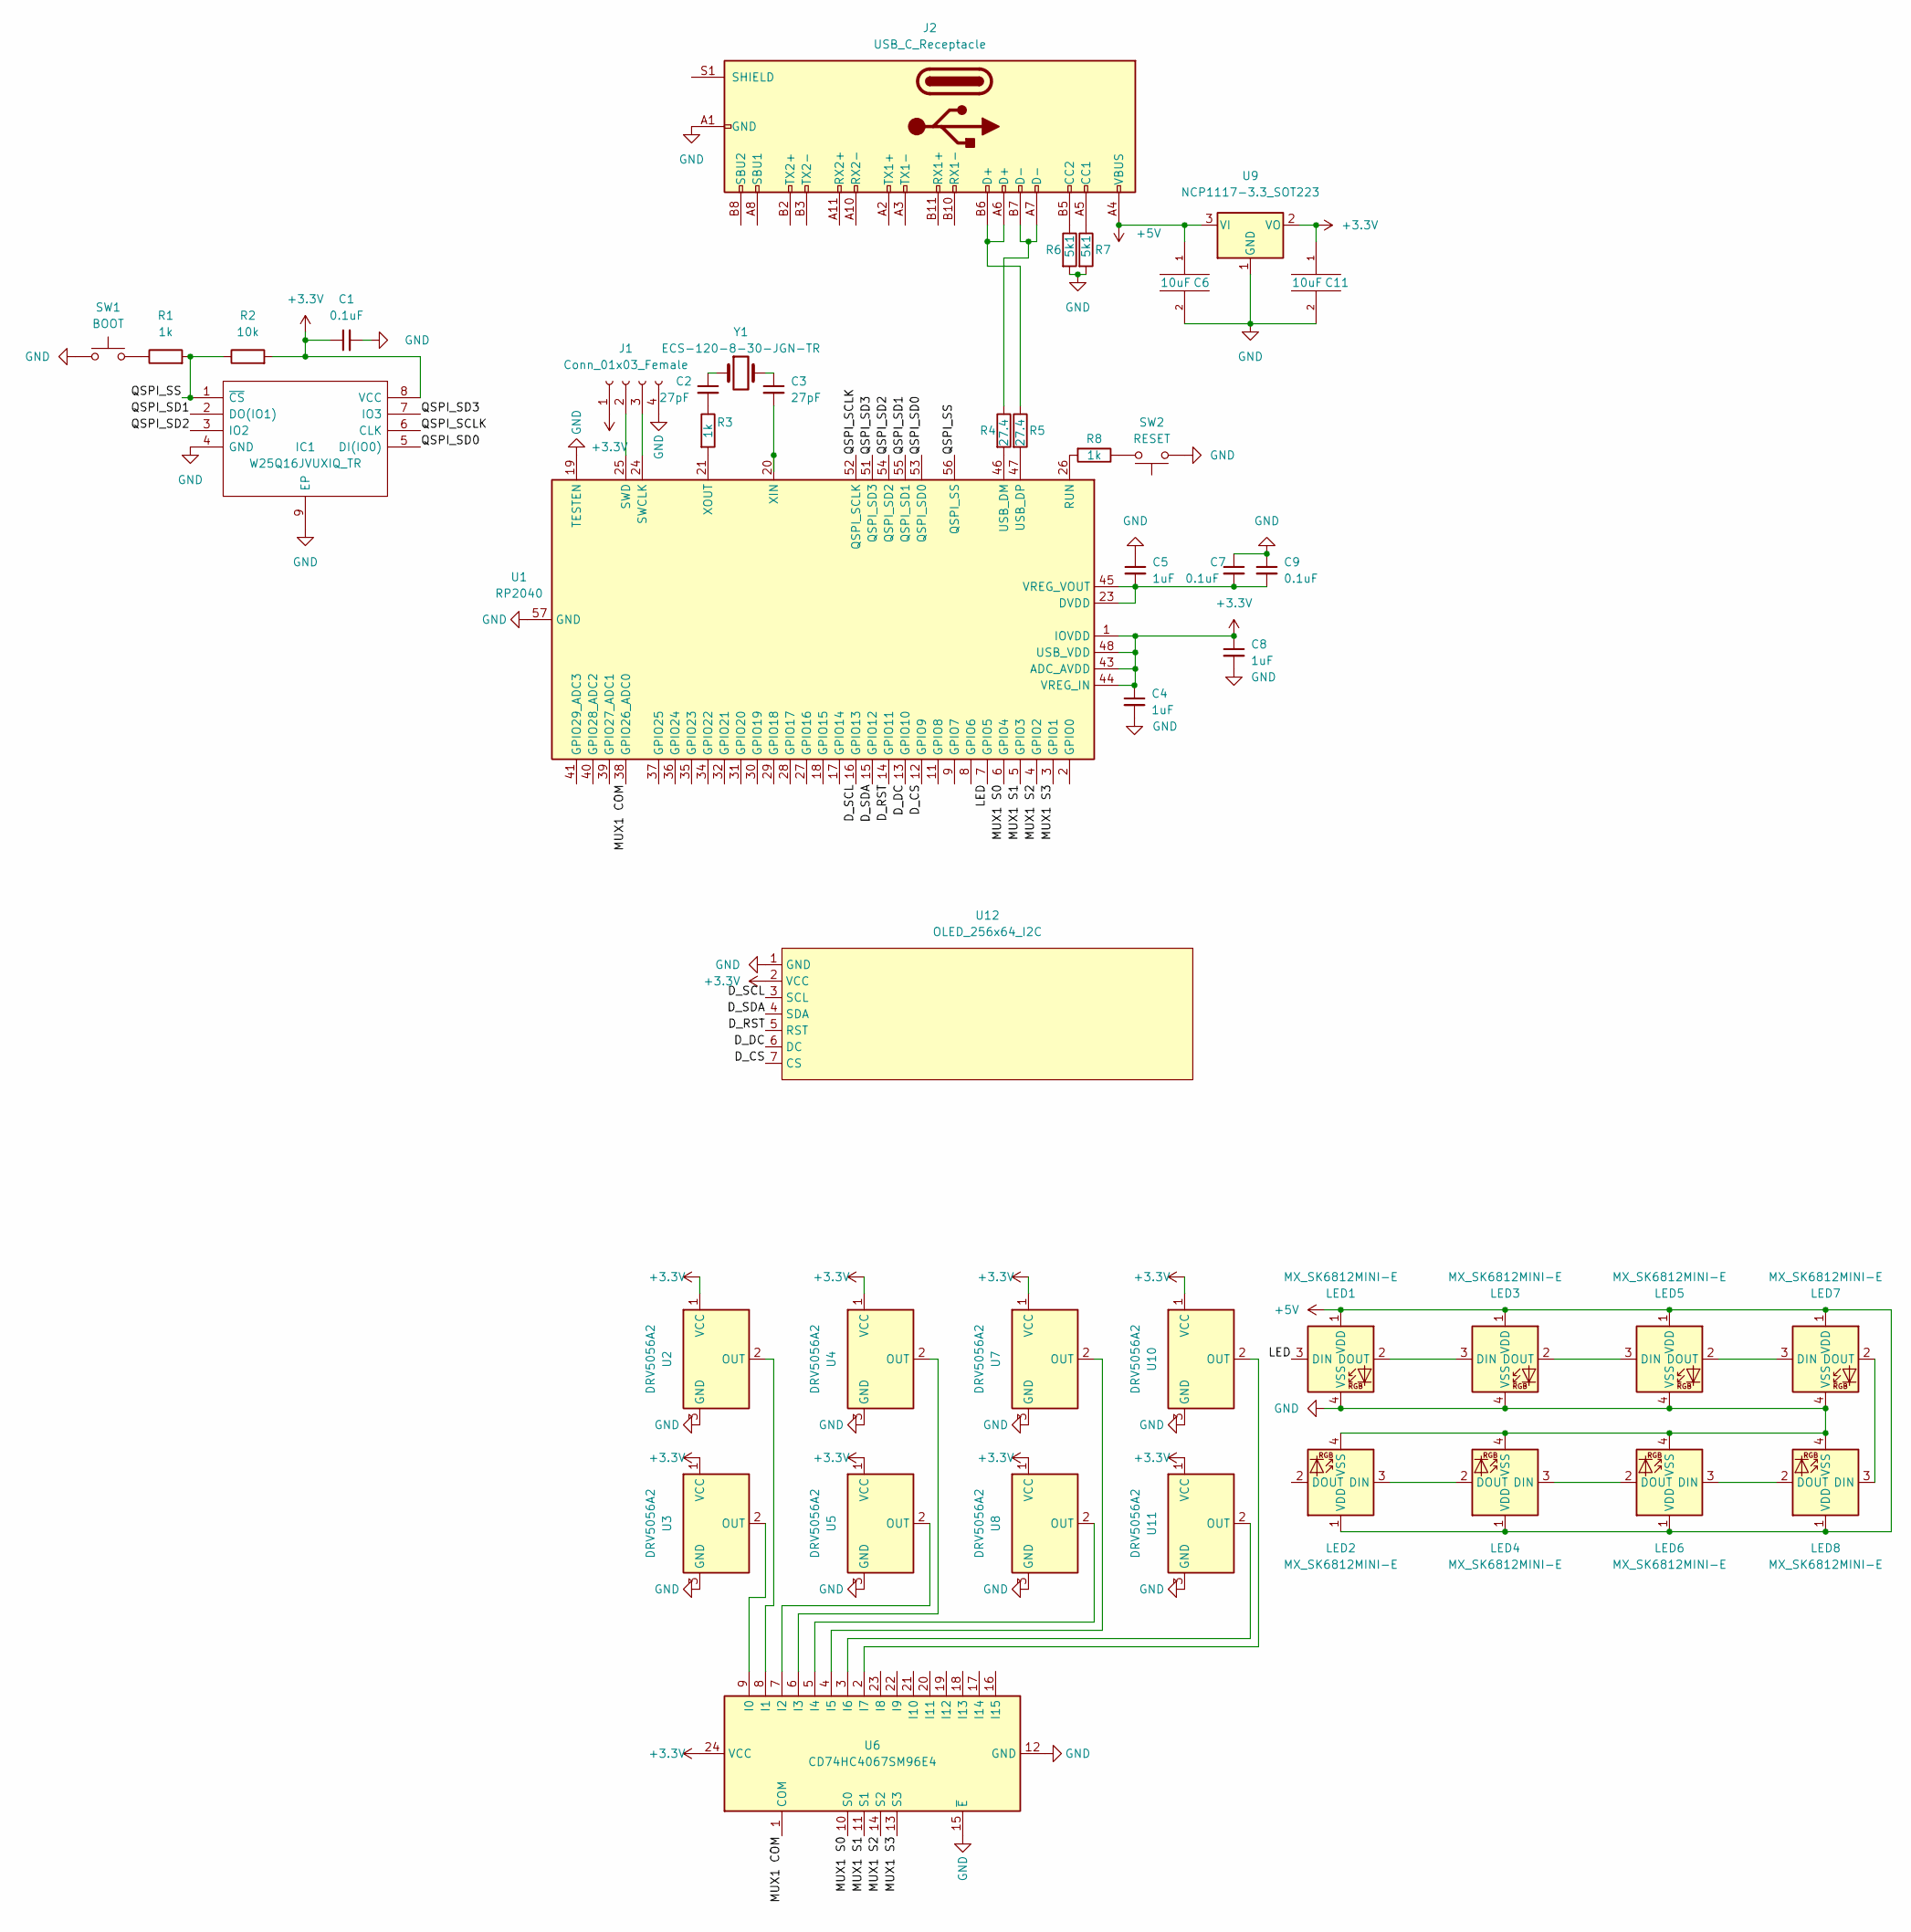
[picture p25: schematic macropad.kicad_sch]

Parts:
C1, C7, C9: 0.1uF; C_0603_1608Metric; MPN MSAST105SB7104KFNB25
C2, C3: 27pF; C_0603_1608Metric; MPN GJM1555C1H270FB01D
C4, C5, C8: 1uF; C_0603_1608Metric; MPN MAASA105CD7105KFCA01
C6, C11: 10uF; C_0603_1608Metric; MPN GRM155R60J106ME15D
IC1: W25Q16JVUXIQ_TR; SON50P300X200X60-9N; Mouser Part Number 454-W25Q16JVUXIQTR
J1: Conn_01x03_Female; PinHeader_1x04_P2.54mm_Vertical
J2: USB_C_Receptacle; USB_C_Receptacle_Amphenol_12401610E4-2A; MPN 12401832E402A
LED1, LED3, LED5, LED7: MX_SK6812MINI-E; LED_MX_SK6812MINI-R; MPN SK6812MINI-E
LED2, LED4, LED6, LED8: MX_SK6812MINI-E; LED_MX_SK6812MINI-R_FLIPPED; MPN SK6812MINI-E
R1, R3, R8: 1k; R_0603_1608Metric; MPN RCC06031K00FKEA
R2: 10k; R_0603_1608Metric; MPN ERJ-3EKF1002V
R4, R5: 27.4; R_0603_1608Metric; MPN CRCW060327R4FKEB
R6, R7: 5k1; R_0603_1608Metric; MPN ERJ-3EKF5101V
SW1: BOOT; SW_Push_1P1T_NO_Vertical_Wuerth_434133025816; MPN 95C06B2GWRT
SW2: RESET; SW_Push_1P1T_NO_Vertical_Wuerth_434133025816; MPN 95C06B2GWRT
U1: RP2040; QFN-56-1EP_7x7mm_P0.4mm_EP3.2x3.2mm; MPN RPI Chip RP2040-7-500
U2, U3, U4, U5, U7, U8, U10, U11: DRV5056A2; DRV505x; MPN DRV5056A2QDBZT
U6: CD74HC4067SM96E4; SSOP-24_5.3x8.2mm_P0.65mm; MPN CD74HC4067SM96E4
U9: NCP1117-3.3_SOT223; SOT-223-3_TabPin2; MPN NCP1117LPST33T3G
U12: OLED_256x64_I2C
Y1: ECS-120-8-30-JGN-TR; Crystal_SMD_5032-2Pin_5.0x3.2mm; MPN ECS-120-8-30-JGN-TR

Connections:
+3.3V: C1.1, C4.1, C8.1, C11.1, IC1.8 (VCC), J1.1, R2.2, U1.1 (IOVDD), U1.10 (IOVDD), U1.22 (IOVDD), U1.33 (IOVDD), U1.42 (IOVDD), U1.43 (ADC_AVDD), U1.44 (VREG_IN), U1.48 (USB_VDD), U1.49 (IOVDD), U2.1 (VCC), U3.1 (VCC), U4.1 (VCC), U5.1 (VCC), U6.24 (VCC), U7.1 (VCC), U8.1 (VCC), U9.2 (VO), U10.1 (VCC), U11.1 (VCC), U12.2 (VCC)
+5V: C6.1, J2.A4 (VBUS), J2.A9 (VBUS), J2.B4 (VBUS), J2.B9 (VBUS), LED1.1 (VDD), LED2.1 (VDD), LED3.1 (VDD), LED4.1 (VDD), LED5.1 (VDD), LED6.1 (VDD), LED7.1 (VDD), LED8.1 (VDD), U9.3 (VI)
/D_CS: U1.12 (GPIO9), U12.7 (CS)
/D_DC: U1.13 (GPIO10), U12.6 (DC)
/D_RST: U1.14 (GPIO11), U12.5 (RST)
/D_SCL: U1.16 (GPIO13), U12.3 (SCL)
/D_SDA: U1.15 (GPIO12), U12.4 (SDA)
/LED: LED1.3 (DIN), U1.7 (GPIO5)
/MUX1 COM: U1.38 (GPIO26_ADC0), U6.1 (COM)
/MUX1 S0: U1.6 (GPIO4), U6.10 (S0)
/MUX1 S1: U1.5 (GPIO3), U6.11 (S1)
/MUX1 S2: U1.4 (GPIO2), U6.14 (S2)
/MUX1 S3: U1.3 (GPIO1), U6.13 (S3)
/QSPI_SCLK: IC1.6 (CLK), U1.52 (QSPI_SCLK)
/QSPI_SD0: IC1.5 (DI(IO0)), U1.53 (QSPI_SD0)
/QSPI_SD1: IC1.2 (DO(IO1)), U1.55 (QSPI_SD1)
/QSPI_SD2: IC1.3 (IO2), U1.54 (QSPI_SD2)
/QSPI_SD3: IC1.7 (IO3), U1.51 (QSPI_SD3)
/QSPI_SS: IC1.1 (~CS), R1.2, R2.1, U1.56 (QSPI_SS)
GND: C1.2, C4.2, C5.1, C6.2, C7.1, C8.2, C9.1, C11.2, IC1.4 (GND), IC1.9 (EP), J1.4, J2.A1 (GND), J2.A12 (GND), J2.B1 (GND), J2.B12 (GND), LED1.4 (VSS), LED2.4 (VSS), LED3.4 (VSS), LED4.4 (VSS), LED5.4 (VSS), LED6.4 (VSS), LED7.4 (VSS), LED8.4 (VSS), R6.2, R7.2, SW1.1, SW2.1, U1.19 (TESTEN), U1.57 (GND), U2.3 (GND), U3.3 (GND), U4.3 (GND), U5.3 (GND), U6.12 (GND), U6.15 (~E), U7.3 (GND), U8.3 (GND), U9.1 (GND), U10.3 (GND), U11.3 (GND), U12.1 (GND)
unnamed: C2.1, Y1.1
unnamed: C2.2, R3.1
unnamed: C3.1, Y1.2
unnamed: J1.2, U1.25 (SWD)
unnamed: J1.3, U1.24 (SWCLK)
unnamed: J2.A5 (CC1), R7.1
unnamed: J2.B5 (CC2), R6.1
unnamed: J2.A6 (D+), J2.B6 (D+), R5.1
unnamed: J2.A7 (D-), J2.B7 (D-), R4.1
unnamed: LED1.2 (DOUT), LED3.3 (DIN)
unnamed: LED2.3 (DIN), LED4.2 (DOUT)
unnamed: LED3.2 (DOUT), LED5.3 (DIN)
unnamed: LED4.3 (DIN), LED6.2 (DOUT)
unnamed: LED5.2 (DOUT), LED7.3 (DIN)
unnamed: LED6.3 (DIN), LED8.2 (DOUT)
unnamed: LED7.2 (DOUT), LED8.3 (DIN)
unnamed: R1.1, SW1.2
unnamed: R8.1, SW2.2
unnamed: R8.2, U1.26 (RUN)
unnamed: R4.2, U1.46 (USB_DM)
unnamed: R5.2, U1.47 (USB_DP)
unnamed: C5.2, C7.2, C9.2, U1.23 (DVDD), U1.45 (VREG_VOUT), U1.50 (DVDD)
unnamed: C3.2, U1.20 (XIN)
unnamed: R3.2, U1.21 (XOUT)
unnamed: U2.2 (OUT), U6.8 (I1)
unnamed: U3.2 (OUT), U6.9 (I0)
unnamed: U4.2 (OUT), U6.6 (I3)
unnamed: U5.2 (OUT), U6.7 (I2)
unnamed: U6.5 (I4), U8.2 (OUT)
unnamed: U6.4 (I5), U7.2 (OUT)
unnamed: U6.2 (I7), U10.2 (OUT)
unnamed: U6.3 (I6), U11.2 (OUT)

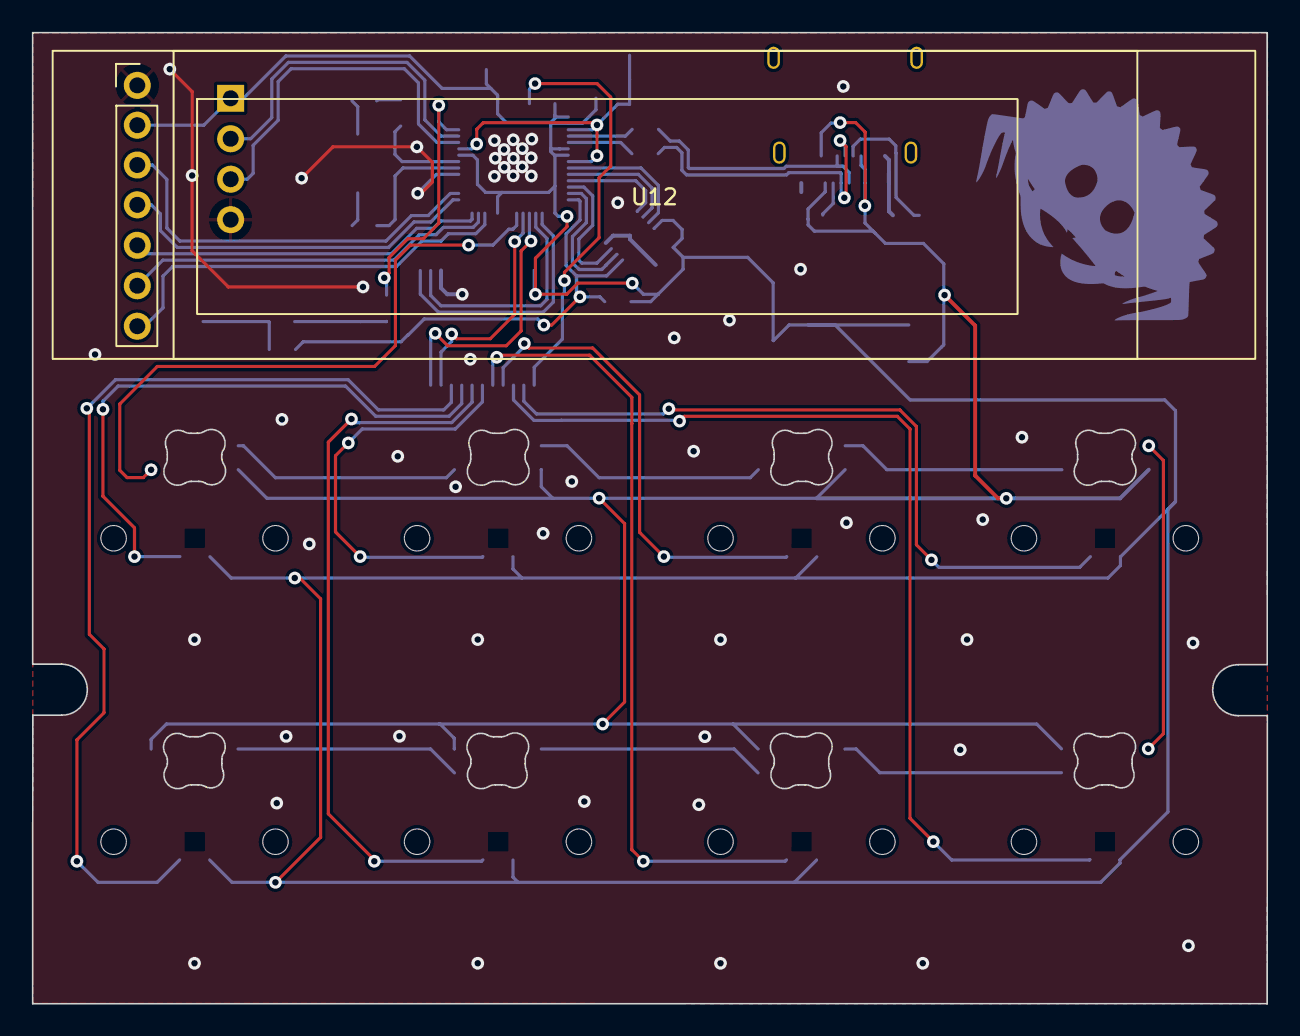
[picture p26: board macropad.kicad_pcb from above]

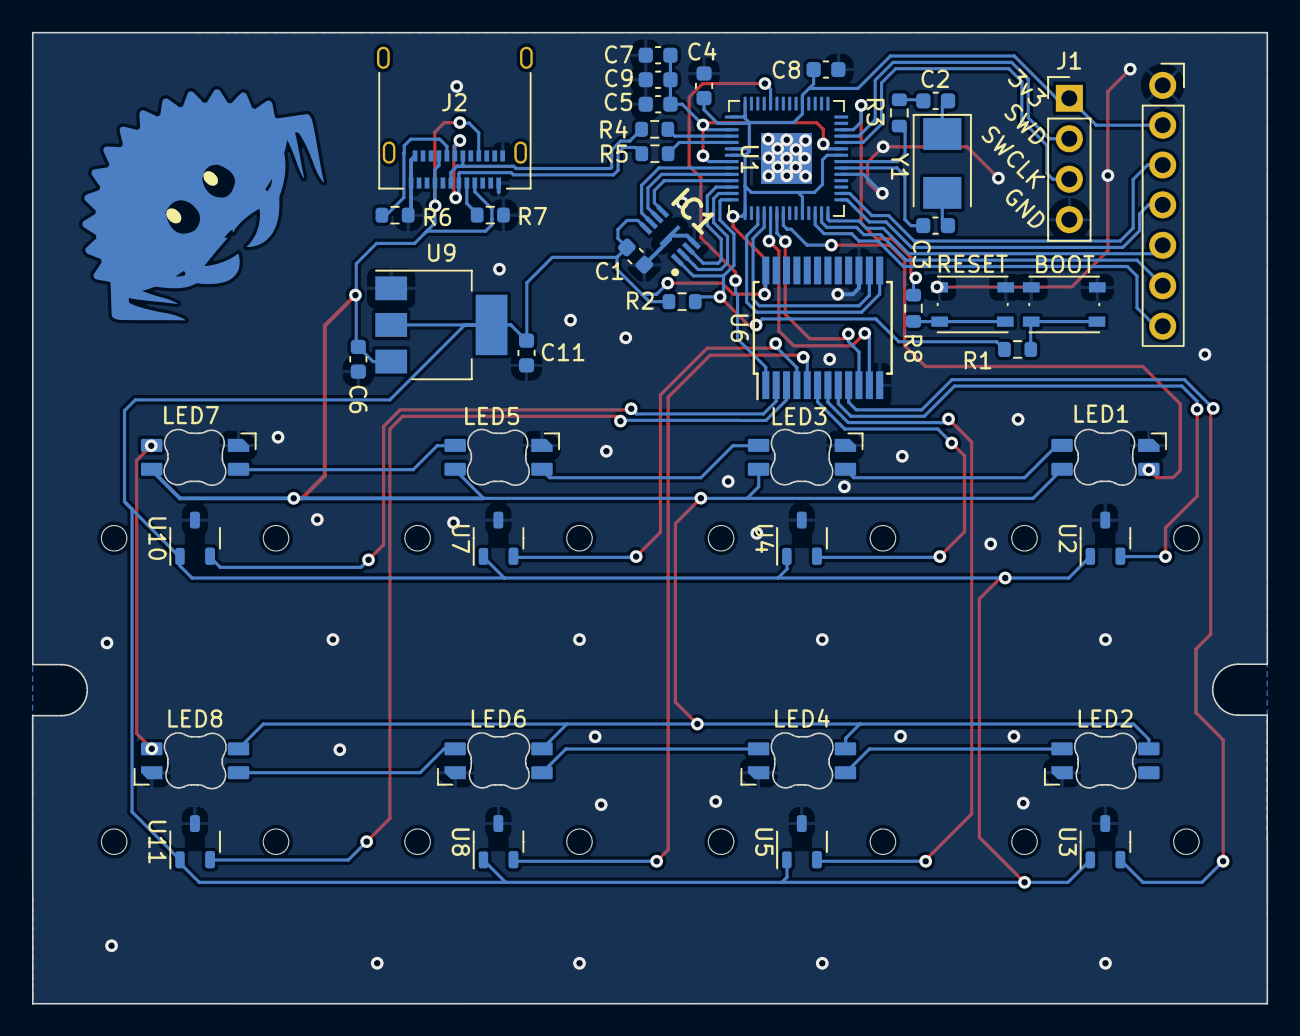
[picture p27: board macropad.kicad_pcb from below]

Board: 2 copper layers, 77.5 x 61.0 mm, 44 parts (43 on the bottom side), 52 nets.

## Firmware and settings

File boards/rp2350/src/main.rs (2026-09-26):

#![no_std]
#![no_main]

use rp235x_hal as hal;

use defmt_rtt as _;
#[cfg(all(target_arch = "arm", target_os = "none"))]
use panic_probe as _;

mod hardware;
mod i2c;
mod layout;
mod scan;
mod uart;
mod usb;

/// Tell the Boot ROM about our application
#[unsafe(link_section = ".start_block")]
#[used]
pub static IMAGE_DEF: hal::block::ImageDef = hal::block::ImageDef::secure_exe();

/// External high-speed crystal on the Raspberry Pi Pico 2 board is 12 MHz.
/// Adjust if your board has a different frequency
const XTAL_FREQ_HZ: u32 = 12_000_000u32;

#[rtic::app(device = crate::hal::pac)]
mod app {
    use crate::{
        Pins,
        hal::{
            self, Adc,
            adc::AdcPin,
            dma::DMAExt,
            timer::{Alarm, Alarm0, CopyableTimer0},
            usb::UsbBus,
        },
        layout,
        scan::ScanState,
        uart::{Message, Uart, UartRole},
        usb::Usb,
    };
    use defmt::info;
    use embedded_hal::digital::InputPin;
    use fugit::MicrosDurationU32;
    use rp235x_hal::{
        Clock,
        gpio::{
            FunctionUart, Pin, PullDown,
            bank0::{Gpio4, Gpio5},
        },
        pac::UART1,
        uart::{UartDevice, ValidUartPinout},
    };
    use usb_device::{bus::UsbBusAllocator, device::UsbDeviceState};
    use usbd_human_interface_device::page::Keyboard;
    use woodox_lib::{
        layout::NUM_SWITCHES,
        matrix::{KeyboardState, NUM_LAYERS},
    };

    #[shared]
    struct Shared {
        #[lock_free]
        keys: KeyboardState,
        #[lock_free]
        scan: ScanState<'static>,
        #[lock_free]
        usb: Usb<UsbBus>,
        #[lock_free]
        uart: Uart<
            UART1,
            (
                Pin<Gpio4, FunctionUart, PullDown>,
                Pin<Gpio5, FunctionUart, PullDown>,
            ),
        >,
        #[lock_free]
        alarm: Alarm0<CopyableTimer0>,
    }

    #[local]
    struct Local {}

    #[init(local = [
        adc: Option<hal::Adc> = None,
        usb: Option<UsbBusAllocator<UsbBus>> = None,
    ])]
    fn init(c: init::Context) -> (Shared, Local) {
        info!("program start");

        unsafe {
            hal::sio::spinlock_reset();
        }

        // ------------------------------------
        // Setup core hardware

        let mut resets = c.device.RESETS;
        let mut watchdog = hal::watchdog::Watchdog::new(c.device.WATCHDOG);
        let sio = hal::Sio::new(c.device.SIO);

        // External high-speed crystal on the pico board is 12Mhz
        let clocks = hal::clocks::init_clocks_and_plls(
            crate::XTAL_FREQ_HZ,
            c.device.XOSC,
            c.device.CLOCKS,
            c.device.PLL_SYS,
            c.device.PLL_USB,
            &mut resets,
            &mut watchdog,
        )
        .ok()
        .unwrap();

        let mut timer = hal::Timer::new_timer0(c.device.TIMER0, &mut resets, &clocks);

        let pins = Pins::new(
            c.device.IO_BANK0,
            c.device.PADS_BANK0,
            sio.gpio_bank0,
            &mut resets,
        );

        info!("core initialization finished");

        // ------------------------------------
        // Setup Mux and ADC for switch scanning

        // Initialize MUX

        let mux = crate::hardware::mux::CD74HC4051::new(
            pins.mux_enable.into_push_pull_output(),
            pins.mux_s0.into_push_pull_output(),
            pins.mux_s1.into_push_pull_output(),
            pins.mux_s2.into_push_pull_output(),
        );

        let dma = c.device.DMA.split(&mut resets);
        *c.local.adc = Some(Adc::new(c.device.ADC, &mut resets));
        let adc = c.local.adc.as_mut().unwrap();

        let mut adc_pin_0 = AdcPin::new(pins.mux1_com.into_floating_input()).unwrap();
        let adc_pin_1 = AdcPin::new(pins.mux2_com.into_floating_input()).unwrap();
        let adc_pin_2 = AdcPin::new(pins.mux3_com.into_floating_input()).unwrap();
        let adc_pin_3 = AdcPin::new(pins.mux4_com.into_floating_input()).unwrap();

        let handedness = pins.handedness.into_floating_input().is_high().unwrap();

        let fifo = adc
            .build_fifo()
            .round_robin((&adc_pin_0, &adc_pin_1, &adc_pin_2, &adc_pin_3))
            .set_channel(&mut adc_pin_0)
            .shift_8bit()
            .enable_dma()
            .start_paused();
        let scan = ScanState::new(mux, dma.ch0, fifo, timer, handedness);

        info!("adc initialization finished");

        *c.local.usb = Some(UsbBusAllocator::new(hal::usb::UsbBus::new(
            c.device.USB,
            c.device.USB_DPRAM,
            clocks.usb_clock,
            true,
            &mut resets,
        )));

        let usb_bus = c.local.usb.as_mut().unwrap();
        let usb = Usb::new(usb_bus);

        let uart_pins = (pins.i2c_sda.into_function(), pins.i2c_sdl.into_function());
        let uart = Uart::new(
            uart_pins,
            &mut resets,
            c.device.UART1,
            clocks.peripheral_clock.freq(),
        );

        let mut alarm = timer.alarm_0().unwrap();
        alarm.enable_interrupt();
        alarm.schedule(MicrosDurationU32::Hz(1000)).unwrap();

        let keys = if handedness {
            // Right Hand
            info!("handedness: right");
            KeyboardState::new(layout::right::keymap())
        } else {
            // Left Hand
            info!("handedness: left");
            KeyboardState::new(layout::left::keymap())
        };

        (
            Shared {
                keys,
                scan,
                usb,
                uart,
                alarm,
            },
            Local {},
        )
    }

    #[task(binds = TIMER0_IRQ_0, shared = [keys, scan, usb, alarm, uart])]
    fn usb_timer_alarm(cx: usb_timer_alarm::Context) {
        // Schedule next USB interrupt instantly
        cx.shared.alarm.clear_interrupt();
        cx.shared.alarm.schedule(MicrosDurationU32::Hz(1000)).unwrap();

        // Do our matrix scan & usb report
        // this should be fixed timing smaller than the USB timer period
        // so complete before the next IRQ
        cx.shared.scan.scan();

        cx.shared.usb.tick(cx.shared.keys, cx.shared.uart);
    }

    #[task(binds = UART1_IRQ, shared = [keys, uart])]
    fn uart_alarm(cx: uart_alarm::Context) {
        cx.shared.uart.intr(cx.shared.keys);
        cx.shared.uart.uart.clear_rx_interrupt()
    }

    #[task(binds = DMA_IRQ_0, shared = [keys, scan, uart])]
    fn scan_dma_completion(cx: scan_dma_completion::Context) {
        let scan = cx.shared.scan;

        if cx.shared.uart.role == UartRole::Secondary {
            scan.dma_completion(cx.shared.keys, |ev| match ev {
                woodox_lib::matrix::KeyboardEvent::Keycode(idx, layer, key) => {
                    cx.shared.uart.send(Message::Keycode((idx, layer, key)))
                }
                woodox_lib::matrix::KeyboardEvent::Layer(layer) => cx.shared.uart.send(Message::Layer(layer)),
            });
        } else {
            scan.dma_completion(cx.shared.keys, |ev| match ev {
                woodox_lib::matrix::KeyboardEvent::Keycode(_, _, _) => (),
                woodox_lib::matrix::KeyboardEvent::Layer(layer) => cx.shared.uart.send(Message::Layer(layer)),
            });
        };
    }
}



hal::bsp_pins!(
    Gpio32 { name: mux_enable },
    Gpio31 { name: mux_s0 },
    Gpio30 { name: mux_s1 },
    Gpio29 { name: mux_s2 },
    Gpio33 { name: led },
    Gpio44 { name: mux1_com },
    Gpio43 { name: mux2_com },
    Gpio42 { name: mux3_com },
    Gpio41 { name: mux4_com },
    Gpio34 { name: d_cs },
    Gpio35 { name: d_dc },
    Gpio36 { name: d_rst },
    Gpio37 { name: d_sda },
    Gpio38 { name: d_scl },
    Gpio4 { name: i2c_sda },
    Gpio5 { name: i2c_sdl },
    Gpio6 { name: i2c_sda_acc },
    Gpio7 { name: i2c_sdl_acc },
    Gpio8 { name: handedness },
);

/// Program metadata for `picotool info`
#[unsafe(link_section = ".bi_entries")]
#[used]
pub static PICOTOOL_ENTRIES: [hal::binary_info::EntryAddr; 5] = [
    hal::binary_info::rp_cargo_bin_name!(),
    hal::binary_info::rp_cargo_version!(),
    hal::binary_info::rp_program_description!(c"Hall Effect Firmware"),
    hal::binary_info::rp_cargo_homepage_url!(),
    hal::binary_info::rp_program_build_attribute!(),
];

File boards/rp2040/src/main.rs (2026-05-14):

#![no_std]
#![no_main]

use hal::multicore::Multicore;
use hal::multicore::Stack;
use rp2040_hal as hal;
use usb_device::class_prelude::*;

use defmt::*;
use defmt_rtt as _;
use panic_probe as _;

use hal::{Adc, clocks, entry, pac, watchdog};

mod hardware;
mod scan;
mod usb;

use woodox_lib::layout;

/// The linker will place this boot block at the start of our program image. We
/// need this to help the ROM bootloader get our code up and running.
#[unsafe(link_section = ".boot2")]
#[used]
pub static BOOT2: [u8; 256] = rp2040_boot2::BOOT_LOADER_GENERIC_03H;

pub const DMA_BUF_SIZE: usize = 4;

static CORE1_STACK: Stack<4096> = Stack::new();

#[entry]
fn main() -> ! {
    info!("program start");

    // ------------------------------------
    // Setup core hardware
    let mut pac = pac::Peripherals::take().unwrap();
    let _core = pac::CorePeripherals::take().unwrap();
    let mut watchdog = watchdog::Watchdog::new(pac.WATCHDOG);
    let mut sio = hal::Sio::new(pac.SIO);

    // External high-speed crystal on the pico board is 12Mhz
    let external_xtal_freq_hz = 12_000_000u32;
    let clocks = clocks::init_clocks_and_plls(
        external_xtal_freq_hz,
        pac.XOSC,
        pac.CLOCKS,
        pac.PLL_SYS,
        pac.PLL_USB,
        &mut pac.RESETS,
        &mut watchdog,
    )
    .ok()
    .unwrap();

    #[allow(unused_variables)]
    let timer = hal::Timer::new(pac.TIMER, &mut pac.RESETS, &clocks);

    let pins = Pins::new(
        pac.IO_BANK0,
        pac.PADS_BANK0,
        sio.gpio_bank0,
        &mut pac.RESETS,
    );

    info!("core initialization finished");

    // ------------------------------------
    // Setup Mux and ADC for switch scanning

    // Initialize MUX
    let mux = hardware::CD74HC4067::new(
        pins.mux1_s0.into_push_pull_output(),
        pins.mux1_s1.into_push_pull_output(),
        pins.mux1_s2.into_push_pull_output(),
        pins.mux1_s3.into_push_pull_output(),
    );

    // Initialize ADC
    let adc = {
        let adc = Adc::new(pac.ADC, &mut pac.RESETS);
        let _adc_pin_0 = pins.mux1_com.into_floating_input();
        let _adc_pin_1 = pins.mux2_com.into_floating_input();
        let _adc_pin_2 = pins.mux3_com.into_floating_input();
        let _adc_pin_3 = pins.mux4_com.into_floating_input();

        let adc = adc.free();
        adc.cs().modify(|_, w| unsafe { w.rrobin().bits(0b01111) });

        adc.cs().modify(|_, w| unsafe { w.ainsel().bits(0) });
        adc.cs().modify(|_, w| w.en().set_bit());
        while !adc.cs().read().ready().bit_is_set() {
            cortex_m::asm::nop();
        }

        info!("adc initialization finished");

        adc
    };

    // ------------------------------------
    // Setup USB BUS
    let usb_bus = UsbBusAllocator::new(hal::usb::UsbBus::new(
        pac.USBCTRL_REGS,
        pac.USBCTRL_DPRAM,
        clocks.usb_clock,
        true,
        &mut pac.RESETS,
    ));

    // ------------------------------------
    // Start switch scan loop on core 1
    let mut mc = Multicore::new(&mut pac.PSM, &mut pac.PPB, &mut sio.fifo);
    let cores = mc.cores();
    let core1 = &mut cores[1];
    let _scan = core1.spawn(CORE1_STACK.take().unwrap(), || scan::scan(adc, mux));

    // ------------------------------------
    // Start usb controlelr loop on core 0
    usb::usb::<hal::usb::UsbBus>(timer, usb_bus)
}

hal::bsp_pins!(
    Gpio0 { name: pull_up },
    Gpio1 { name: mux1_s3 },
    Gpio2 { name: mux1_s2 },
    Gpio3 { name: mux1_s1 },
    Gpio4 { name: mux1_s0 },
    Gpio5 { name: led },
    Gpio26 { name: mux1_com },
    Gpio27 { name: mux2_com },
    Gpio28 { name: mux3_com },
    Gpio29 { name: mux4_com },
    // Gpio9 { name: d_cs },
    Gpio10 { name: d_dc },
    Gpio11 { name: d_rst },
    Gpio12 { name: d_sda },
    Gpio13 { name: d_scl },
);

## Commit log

2023-01-02 finish left hand pcb
    [right_hand.kicad_sch, woodox.kicad_pcb, woodox.kicad_sch]
2023-02-18 finish macropad pcb
    [ECS-2520MV-080-CN-TR.step, LM3940IMPX-3.3_NOPB.step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]
2023-03-06 fix multiple issues with macropad pcb
    [macropad-B_Cu.gbr, macropad-B_Mask.gbr, macropad-B_Paste.gbr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]
2023-03-06 dma and adc schenanigans
2023-03-11 flip usb data lines to correct orientation
    [macropad.kicad_pcb, macropad.kicad_sch]
2023-03-24 rework macropad usb data lines
    [macropad.kicad_pcb]
2026-03-07 whatever the fuck i all did
    [case.kicad_pcb, left_hand.kicad_sch, macropad.kicad_pcb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]
2026-03-31 redox woodox left hand pcb
    [left_hand.kicad_sch, right_hand.kicad_sch, woodox-rounded.kicad_pcb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]
2026-03-31 cleanup pcb
    [woodox.kicad_pcb, woodox.kicad_sch]
2026-04-01 double sided pcb
    [woodox.kicad_pcb, woodox.kicad_sch]
2026-04-01 usb-c interconnects and expansion solder pads
    [woodox.kicad_pcb, woodox.kicad_sch]
2026-04-01 pcb images
2026-04-02 rp2350 redesign
    [woodox.kicad_pcb, woodox.kicad_sch]
2026-04-02 fix lints
    [woodox.kicad_pcb, woodox.kicad_sch]
2026-04-03 mounting holes
    [woodox.kicad_pcb, woodox.kicad_sch]
2026-05-14 update firmware deps & fixup
    [main.rs, scan.rs, usb.rs]
2026-05-16 reorganize file structure
    [CON_BM02B-ACHSS.step, CON_MJ-4PP-9.step, CON_SM02B-SRSS-TB.step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]
2026-05-24 start redesign pre rtic
    [cd74hc4051.rs, dma.rs, main.rs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]
2026-05-25 usb timers
2026-06-05 reworked keymap/keyboard state and switch calucations
    [main.rs, mod.rs, usb.rs]
2026-06-08 !wip test hall sensors
2026-06-11 unfuck and test a bunch of sensor stuff
2026-06-13 review switch tests and fix rapid trigger
2026-06-13 invert switch distance logic to use compression travel
2026-06-14 fix dma buffer mux mapping not being consistent
    [main.rs, mod.rs, usb.rs]
2026-06-17 fix stupid default switch trig limits
2026-09-23 move key and switch layout to board and sepperated hands
2026-09-23 add basic startup calibration of offset
2026-09-25 uart comms work!
2026-09-26 adjust led footprint and board outline
    only minor adjustments for step export to make a clean closing outline
    [keyboard-plate.dxf, woodox.kicad_pcb, woodox.step]
2026-09-26 uart fixes
2026-10-01 set uart rate to 1Mhz
